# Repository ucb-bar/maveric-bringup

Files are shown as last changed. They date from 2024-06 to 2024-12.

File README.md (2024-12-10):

# Maveric Bringup

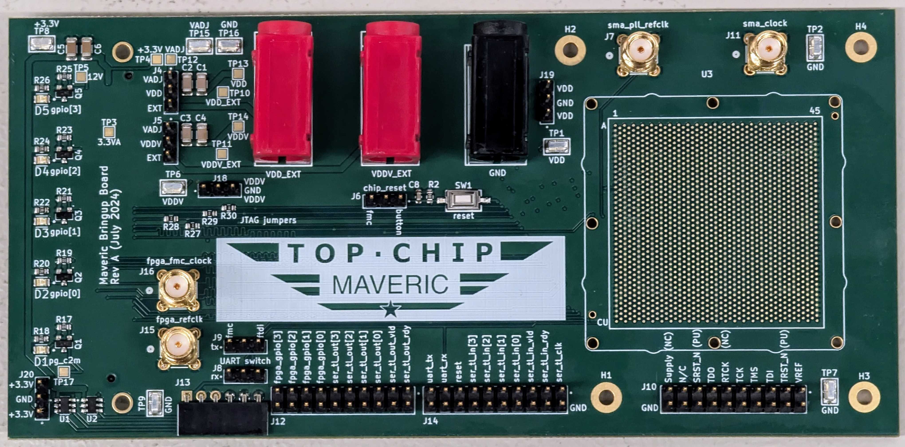
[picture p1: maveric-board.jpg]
Maveric Board


## Timeline

- 7/12 5pm: submitted order
- 7/12 7pm: review done
- 7/12 8pm: production files sent, confirmed
- 7/14 2am: parts placement sent, confirmed
- 7/18 7pm: board fab done
- 7/20 1am: board assembly done
- 7/21 8pm: shipped
- 7/23 2pm: delivered to BWRC
- Collaterals from JLCPCB are in `maveric-board/07_22_2024-jlcpcb`

## Test Plan

### FPGA Devboard

- Things to consider: cost, FPGA type, host interface, DRAM, connector + voltages, form factor
- Desires
  - Low cost (< $3k)
  - Small FPGA (fast bitstream generation and programming)
  - High bandwidth host interface (but NO PCIe / Ethernet, UART is OK but USB-FIFO is ideal)
  - Some DRAM, just 512 MiB is enough
  - FMC connector with board acting as carrier (FMC+ is OK, backwards compatible with FMC) (FMC-LPC is sufficient), 1.2V VADJ is necessary
  - Small board form factor
- [Xilinx VCU118](https://www.xilinx.com/products/boards-and-kits/vcu118.html)
  - $9k
  - Virtex Ultrascale+
  - USB-UART / PCIe with riser
  - 2x 2.5 Gib DDR4
  - FMC-HPC (ASP-134486-01), VADJ = 1.8V by default, can go down to 1.2V if FMC EEPROM is programmed or if system controller is overridden (intricate, but doable)
  - Large PCIe card
- [Opal Kelly XEM7350](https://opalkelly.com/products/xem7350/)
  - $1.5k
  - Kintex 7
  - USB3 with special RTL + drivers (Opal Kelly FrontPanel) with 340 MiB/s bandwidth
  - 512 MiB DDR3
  - FMC-HPC (-K160T part) (ASP-134486-01) (mates with ASP-134488-01), (34 (LA, Vadj) + 24 (HA, Vadj) + 22 (HB, Vio) = 80 IO pins), Vadj easy to set to 1.2V permanently, Vio comes from FMC_VIO_B_M2C (which can just be shorted to Vadj on the mezzanine)
  - Pretty small card
- [Digilent Nexys Video](https://digilent.com/shop/nexys-video-artix-7-fpga-trainer-board-for-multimedia-applications/)
  - $550
  - Artix 7
  - USB-UART / Ethernet / FT2232 (FTDI USB-FIFO chip, kind of an old part with iffy drivers)
  - 512 MiB DDR3
  - FMC-LPC (ASP-134603-01), 34x2 pins, Vadj set to 1.2V by default, easy

#### Mechanical Sketch

- [XEM7350 Mechanical Drawing](https://docs.opalkelly.com/wp-content/uploads/2022/05/XEM7350-MechanicalDrawing.pdf)
  - 4x standoffs for the FPGA devboard that exceed 6.5mm in height, 2.70mm hole diameter (use M2 standoff kit, M2 has clearance hole diameter of 2.6mm)
  - 2x standoffs for the chip motherboard that are likely around 18.5mm (will use same hole diameter)

### Chip Signals + Debug

[Bump map](https://bwrcrepo.eecs.berkeley.edu/kimsea8209/rtml-intech22-chipyard/-/blob/rtml-jerry/vlsi/specs/rtml-bumps.yml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) is saved in the `bumpmap` folder.
See the `README.md` in that folder for details.

#### Signals

- **JTAG**
  - Directly place the JTAG header on the motherboard. Don't daisy chain chip JTAG to FMC JTAG. Don't pass JTAG signals through FMC.
  - Use [this JTAG debugger](https://www.olimex.com/Products/ARM/JTAG/ARM-USB-OCD-HL/) (**-HL variant** works down to 0.65V)
    - [Digikey link](https://www.digikey.com/en/products/detail/olimex-ltd/ARM-USB-OCD-HL/21662466) ($58.79)
  - Use a USB optoisolator if we're scared
    - [Olimex link](https://www.olimex.com/Products/USB-Modules/USB-ISO/)
  - Standard [20-pin ARM JTAG header](https://developer.arm.com/documentation/101416/0100/Hardware-Description/Target-Interfaces/ARM-Standard-JTAG)
    - 2 rows × 10 pins at 0.1" step
    - [This will do, Digikey link](https://www.digikey.com/en/products/detail/sullins-connector-solutions/SBH11-PBPC-D10-ST-BK/1990065)
    - [Another Molex alternative that's much more expensive for some reason](https://www.digikey.com/en/products/detail/molex/0702462002/760185)
- **UART**
  1. Wire through FMC if we want to use the FPGA to drive chip UART
  2. Break out to headers to jump into the [Digilent Pmod USBUART](https://digilent.com/reference/pmod/pmodusbuart/reference-manual?redirect=1)
  - Requires level translation from 1.2V to 3.3V
  - Use jumpers to select between the 1) and 2) options for interacting with the chip via UART
    - Use standard 0.1" pitch 3x1 male headers and a shorting jumper for each wire (RX/TX)
    - [Shorting jumper - Digikey](https://www.digikey.com/en/products/detail/sullins-connector-solutions/QPC02SXGN-RC/2618262)
- **Serial TL**
  - Break out every signal (4 data + 1 valid + 1 ready = 6 pins/direction, 12+1 clock) to header pins via 0 Ohm resistor
  - Length match all signals roughly, within 10 mm
  - Make sure all signals land in same FPGA IO bank and land on pins with roughly the same [routing length on the devboard](https://pins.opalkelly.com/pin_list/XEM7350)
- **Chip reset**
  - Reset is active high. It is asynchronous. It is internally synchronized to the core clock domain on the falling reset edge.
  - Break out reset to header pin
  - ~~Drive a LED to indicate reset state with driver FET (make sure V_{gs,max} << 1.2V)~~ (bad idea to add more load on the reset net)

#### Clocking

- **Serial TL clock**
  - Always driven from FPGA FMC along with the rest of serial TL signals
  - No impedance control, but serial TL traces are roughly length matched (yeah I know this is overkill)
- **Core clock**
  - Can be driven by:
    1. FPGA via a regular GPIO pin over FMC
    2. External clock generator
  - Trace should have 50 Ohm impedance. Use SMAs to jump the FPGA clock to the chip clock and to receive the external clock (3x SMA total).
  - [Use shunt 50 Ohm termination near the chip clock pin](https://electronics.stackexchange.com/questions/646896/cannot-trigger-digital-logic-because-half-of-source-voltage-is-lost-in-impedance)
    - This works fine for the FPGA clock driver since it has low-Z output impedance. It will drive rail-to-rail 1.2Vpp at the chip.
    - This is a problem for the external clock generator since it has 50 Ohm series output impedance. It will drive 0.6Vpp at the chip nominally, so it will have to drive 2.4Vpp at the source for the chip to see 1.2Vpp.
- **PLL refclk**
  - Only comes from external clock generator with 50 Ohm driving impedance
  - Since it drives a high-Z IO cell, no termination is required, and Vpp on the generator should be set to 1.2V

#### Power

- Chip has 2 power inputs (VDD = core, VDDV = IO)
- VDDV and VDD can come from:
  1. External supply via banana plug (for current measurement)
  2. VADJ from FMC (nominally 1.2V) ()
  - Jumpers are used to select between 1) and 2)
- PCB considerations
  - Use 2 separate layers for VDD and VDDV so we can via directly to them from anywhere
  - Use 2 separate layers for GND
  - Front and back copper used for signal routing + ground pour
  - Route 3V3 FMC supply on top copper (we aren't using the other FMC supplies like 3V3AUX and 12V)
- Short all grounds together (FMC + banana plug ground)
- Headers for Vadj, VDD, GND, all FMC provided supplies

#### JTAG Pull-ups(downs)

Here is what all the various vendors have to say about JTAG pullup / pulldown resistors on JTAG nets from the target side.

- Xilinx
  - TDI + TMS pullup to VCC via 4.7k
  - TCK + TDO floating
- Altera
  - TDI + TMS weak pullup via 10k (TDI optional)
  - TCK weak pulldown via 1k
  - TDO floating
- ARM
  - TMS + TDI + TDO + nSRST + nTRST pullup
  - TCK pulldown
  - TRCK pulldown
  - All resistors should be 10k, except 4.7k for nSRST
- Lattice
  - TMS + TDI + TDO pullup via 4.7k
  - TCK pulldown via 4.7l
  - 100nF cap between VREF and GND near JTAG header

OK, after looking at all this conflicting information, I have made a decision.

- TMS + TDI + TDO pullup via 4.7k
- TCK pulldown via 4.7k
- RTCK floating
- TTRST_N + TSRST_N pullup via 4.7k (not going to chip, just in case the adapter wants to see these nets, this might be overkill and stupid)
- 100nF cap near connector on VREF
- Make sure all of these are easy to desolder if necessary

##### Decap

- Same strategy as hyperscale chip
- 10uF caps, 0603, place on backside of socket. Be wary of backside KOZ which are quite unusual.
- Use 100uF caps on VDD, VDDV, 3V3 supplies
- Use 10uF caps for decap near level shifters

### Chip Board to FPGA Connector

- Just use FMC, don't bother with adding the FMC EEPROM, loop FMC JTAG on the board with no daisy chaining, N/C FMC I2C
  - [FMC FAQ](https://www.vita.com/FMC-FAQ)
    - Attaching a LPC mezzanine to a HPC carrier is just fine as long as none of the HPC pins are used on the mezzanine
  - [Samtec's VITA 57.1 part picker](https://www.samtec.com/standards/vita/fmc/)
    - We can choose any HPC/LPC connector with/without leaded solder depending on what connectors are [in stock at JLCPCB](https://jlcpcb.com/parts/all-electronic-components)
- FMC powergood (C2M)
  - Add LED indicator + header probe point

## Schematic Review

- [x] Make sure all the chip IOs are represented and properly connected
  - ~~We seem to have used HSDIFF Q4 bumps (Hyperscale chip used HSDIFF Q3 for chip A and HSDIFF Q4 for chip B)~~
  - There are no clock taps, there isn't a `custom_boot` pin either
  - OH NO, I did make a mistake here. Refer to [this spreadsheet](https://docs.google.com/spreadsheets/d/1MSgKrY-m9DyHcFtSvew053FMCg2KrU9-J1SnmbLqwV8/edit#gid=0) for the correct mappings
- [x] Check clocking
  - [x] Is the PLL refclk terminated on-chip?
- [x] Verify UART directionality
- [x] Make sure power topology is correct
- [x] Make sure all debug functionality is available
- [x] Make sure decap is sufficient
- [x] Does the stackup look reasonable?
- [x] Is everything sane mechanically?

### Notes from Review

- [x] Add a 3 pin header to select reset coming from either FPGA or a button
- [x] 6 pin female header for PMOD USBUART
- [x] Add some more ground probe points (header pin + loop pin things) (4x around the PCB)
- [x] bring in JTAG signals onto the FPGA too via FMC
- [x] fix up the signal name mappings on the schematic
- [x] allocate one more layer for signal routing, combine VDD/VDDV into one layer
- [x] add holes next to FMC connector
- Length matching is unnecessary
- Support UART to Pmod through FPGA and with board headers directly
- Termination shouldn't cause any issues
- Make sure you have lots of test points, lots of ground test points too, make sure every probe for a signal has a short path to ground nearby
- Make sure the JTAG clock is exposed on a header pin
- Make sure you have standoffs near the FMC connector

## PCB CAD

### Considerations

- [Hyperscale test plan slides](https://docs.google.com/presentation/d/1U_Xe0r3WAxrghMTiEDUyeD21PqD4RekB/edit#slide=id.g2c498c81fbe_0_5S)
  - Contains some clocking and PLL and reset notes
- Plan is to use JLCPCB with 6+ layer 2mm board, 2U" ENIG, epoxy filled vias (if via-in-pad is required), 0.15mm min vias, uncontrolled impedance
  - Ideally I can relax the min via diameter, but it may not be possible with the fine BGA pitch. Via-in-pad might be necessary to make routing doable with few layers. Increase layers if required: maybe we can get away with 4 even.
  - Plan is to also do assembly with JLCPCB and get just fully assembled boards. I have verified all parts are in stock and all symbols on schematic are annotated with their 'JLCPCB Part #'.
- [JLCPCB PCB Design Rules](https://jlcpcb.com/capabilities/pcb-capabilities)
  - min 0.25mm BGA pads - OK
  - hole to hole clearance 0.5mm - OK
  - 0.09mm min trace width, 0.09 min trace spacing - seems sufficient for BGA escape
- [JLCPCB BGA Design Notes](https://jlcpcb.com/help/article/243-BGA-Design-Guidelines---PCB-Layout-Recommendations-for-BGA-packages)
  - 0.10mm min trace to BGA pad spacing
  - Everything still seems good enough
- [JLCPCB via-in-pad notes](https://jlcpcb.com/help/article/122-Via-Covering:-Tented,-Untented,-Plugged,-Epoxy-Filled-and-Copper-epoxy-filled)
  - 6+ layer boards come with epoxy filled vias for free! Pricing is insanely cheap for via-in-pad. Vias must be smaller than 0.5mm for full coverage.
- Someone has drafted [KiCad DRC rules for JLCPCB](https://gist.github.com/darkxst/f713268e5469645425eed40115fb8b49?permalink_comment_id=4818217) which I can use for reference
- Someone has tried to [escape a 0.5mm pitch BGA](https://www.eevblog.com/forum/altium/altium-jlcpcb-and-0-65mm-bga/) and it seems fine - just need to relax some design rules and make sure the hole clearance rule is specified correctly
- Another [via-in-pad attempt for 0.5mm pitch BGA](https://electronics.stackexchange.com/questions/676149/how-to-escape-0-5mm-ball-grid-array-pins) - seems possible with via-in-pad

### Stackup

- [JLCPCB Stackups](https://jlcpcb.com/impedance)
- 6 layer, 2mm thickness, 1oz outer copper weight, 0.5oz inner copper weight
- **Chosen Stackup**: JLC06201H-3313

| Layer | Material Type | Thickness | Purpose |
| --- | --- | --- | --- |
| F.Cu | Copper | 0.035mm | Signal, 3V3 (GND pour)|
| Prepreg | 3313*1 | 0.0994mm  | - |
| In1.Cu | Copper | 0.0152mm  | GND |
| Core | Core | 0.7mm | - |
| In2.Cu | Copper | 0.0152mm  | VDD, VDDV |
| Prepreg | 7628*1 | 0.2028mm  | - |
| In3.Cu | Copper | 0.0152mm  | Signal (GND pour) |
| Core | Core | 0.7mm | - |
| In4.Cu | Copper | 0.0152mm  | GND |
| Prepreg | 3313*1 | 0.0994mm  | - |
| B.Cu | Copper | 0.035mm | Signal (GND pour) |

- The stackup looks like (F.Cu, In1.Cu) | (In2.Cu, In3.Cu) | (In4.Cu, B.Cu) (i.e. 2-2-2)
- The first and third pairs are strongly coupled and the second pair has more separation

### Controlled Impedance Traces

- [JLCPCB Controlled Impedance Calculator](https://jlcpcb.com/pcb-impedance-calculator)
  - With the above stackup for 50 Ohm single-ended (non coplanar) (microstrip) on top copper with ground on In1.Cu
  - Trace width: **6.16 mils**

### Design Notes

#### UNI2 Socket

- Unit A-D: HSDIFF_{1-18}_{Q1-4}
- Unit E-H: IODIFF_{1-41}_{Q1-4}
- Unit I/J: Q1_{VDD, VDDV/VDDH}
- Unit K/L: Q2_{VDD, VDDV/VDDH}
- Unit M/N: Q3_{VDD, VDDV/VDDH}
- Unit O/P: Q4_{VDD, VDDV/VDDH}
- Unit Q-Y: VSS

#### FMC Terminal Selection

Possible parts [we can choose from](https://www.samtec.com/standards/vita/fmc/).
I would avoid tin-lead parts just because JLCPCB uses non-leaded solderpaste, and I'm unsure if reflow will work properly.
Also noting stock from JLCPCB.

- 8.5mm, lead-free, HPC: ASP-134602-01
  - 0 stock, $24.63 / part
- 8.5mm, lead-free, LPC: ASP-134606-01
  - 0 stock, $22.24 / part
- 10mm, lead-free, HPC: ASP-134488-01
  - 0 stock, listed as unavailable
- 10mm, lead-free, LPC: ASP-134604-01
  - 9 stock, $15.30 / part, still requires pre-order

- C2M = FPGA to motherboard = connector outputs
- M2C = motherboard to FPGA = connector inputs

#### FMC Pin to Socket Pin Mapping

- Use [XEM7350 Pins](https://pins.opalkelly.com/pin_list/XEM7350#) as reference for length matching. Keep all pins on the same FPGA IO bank ideally. We can choose from IO banks 15 or 16. We should keep to trace lengths (FMC socket to FPGA) around 80mm (78-82mm).

| Signal | FMC Net Name  | FMC Pin | Trace Length on XEM7350 (mm)  | FPGA IO Bank (XEM 7350) | FPGA Pin (XEM 7350) | FPGA Pin (Nexys Video)  | Notes |
| --- | --- | --- | --- | --- | --- | --- | --- |
| serial_tl_clock | LA_00_P_CC | G6 | 79.41 | 15 | H17 | K18 | |
| serial_tl_in_ready | LA_03_P | G9 | 79.53 | 15 | A18 | N18 | |
| serial_tl_in_valid | LA_03_N | G10 | 79.51 | 15 | A19 | N19 | |
| serial_tl_in_bits\[0\] | LA_06_P | C10 | 79.61 | 15 | C19 | N22 | |
| serial_tl_in_bits\[1\] | LA_06_N | C11 | 79.65 | 15 | B19 | M22 | |
| serial_tl_in_bits\[2\] | LA_10_P | C14 | 79.66 | 15 | B17 | K21 | |
| serial_tl_in_bits\[3\] | LA_10_N | C15 | 79.65 | 15 | A17 | K22 | |
| serial_tl_out_ready | LA_05_P | D11 | 78.61 | 15 | C17 | M21 | |
| serial_tl_out_valid | LA_05_N | D12 | 78.63 | 15 | C18 | L21 | |
| serial_tl_out_bits\[0\] | LA_09_P | D14 | 79.63 | 15 | L19 | H20 | |
| serial_tl_out_bits\[1\] | LA_09_N | D15 | 79.63 | 15 | L20 | G20 | |
| serial_tl_out_bits\[2\] | LA_15_P | H19 | 79.79 | 15 | K16 | L16 | |
| serial_tl_out_bits\[3\] | LA_15_N | H20 | 79.74 | 15 | K17 | K16 | |
| clock | LA_01_P_CC | D8 | 79.68 | 15 | G17 | J20 | via SMA cable jumper |
| reset | LA_21_P | H25 | 80.45 | 15 | G15 | E19 | |
| uart_rx | LA_02_P | H7 | 83.66 | 15 | G19 | M18 | via selection jumper |
| uart_tx | LA_02_N | H8 | 83.65 | 15 | F20 | L18 | via selection jumper |
| fpga_refclk | CLK0_M2C_P | H4 | 82.74 | 15 | E18 | J19 | to lock FPGA PLL to external clock source |
| fpga_gpio\[0\] | LA_14_P | C18 | 77.23 | 15 | H16 | J22 | to header + LED |
| fpga_gpio\[1\] | LA_14_N | C19 | 77.24 | 15 | G16 | H22 | to header + LED |
| fpga_gpio\[2\] | LA_27_P | C26 | 77.01 | 16 | D9 | B20 | to header + LED |
| fpga_gpio\[3\] | LA_27_N | C27 | 77.10 | 16 | D8 | A20 | to header + LED |
| jtag_tdi | LA_23_P | D23 | 81.08 | 16 | F14 | B21 | |
| jtag_tdo | LA_23_N | D24 | 81.09 | 16 | F13 | A21 | |
| jtag_tms | LA_26_P | D26 | 79.86 | 16 | C9 | F18 | |
| jtag_tck | LA_26_N | D27 | 79.82 | 16 | B9 | E18 | |

#### Extra Things to Buy

- Olimex JTAG debugger
- PMOD USB-UART
- A set of jumper cables (male to female)
- M2 standoff kit
- Header pin shorting jumpers
- FPGA devboard

#### Assembly Notes

- DNP the UNI2 socket
- Do not wave solder any through-hole components, hand-solder instead

## Tasks

- [x] Check FMC connector footprint [d:6/10]
  - [x] Dimension check: All dimensions check out, I drew some additional things on the silkscreen
  - [x] Solderpaste check: Specifically check solderpaste layer expansion. Pad 25 mils, soldermask expansion 4 mils (default, not that critical), solder paste 35 mils! So yes I adjusted the solder paste clearance.
- [x] Add FMC LPC symbol [d:6/10]
- [x] Wire FMC connector on schematic [d:6/10]
  - [x] Connect power supplies to globals and hierarchical outputs
  - [x] Add FPGA GPIOs
  - [x] Connect various things to GND / PWR
  - [x] Connect chip signals to FMC. Pin planning: want roughly equal delays on all serialtl nets.
  - [x] Add GND/VADJ drivers for unused FMC nets
    - Just to make sure FPGA can read things off the FMC connector
- [x] Add debug headers [d:6/10]
  - [x] 20pin header symbol + footprint + part
  - [x] 3pin header symbol + footprint + part
  - [x] 0 Ohm resistor symbol + footprint + part
  - [x] Add serialTL debug via 0Ohm resistors
  - [x] Add GPIO debug (direct)
- [x] Add terminal blocks for external supplies
  - [x] Add black banana plug symbol + footprint + part
  - [x] Add red banana plug symbol + footprint + part
- [x] Split FPGA and external supplies via jumper [d:6/12]
- [x] Add power domain probe points [d:6/12]
- [x] Add UART headers + jumpers [d:6/12]
- [x] Add UART level shifter [d:6/12]
- [x] Add JTAG headers
- [x] Add JLCPCB part for chip 10u decap
- [x] Add PG FPGA GPIO LEDs [d:6/14]
  - The LEDs on the hyperscale board seem like a waste. Seeing an 'on' LED for VDD doesn't prove anything lol.
  - I only care about the GPIOs and PG from the carrier to mezzanine (which are all slow signals)
  - No need to add an LED on the reset net, we already have a probe point which is sufficient (adding a LED will add NMOS gate cap and shunt resistor, which could retard the rise/fall time)
  - [x] Pick out all the components (2 resistors, MOSFET, LED)
  - [x] LED footprint + 3D
  - [x] MOSFET footprint + 3D
  - [x] Pick current limit resistor
- [x] Add clock nets with impedance control [d:6/14]
  - Fpga output impedance is uncontrolled (very low) impedance lvcmos12 IO standard
  - Terminate with shunt 50 Ohm that the Fpga can use
  - The clock generator will have to output 2x Vpp swing
  - [x] Sketch out clocking strategy
- [x] Add extra trigger refclk for the fpga pll to lock serial tl clock to core clock (if needed to mitigate async crossing issues) [d:6/16]
- [x] Add and check UNI2 socket footprint [d:6/16]
  - Check non-plated through holes, check pad spacing and diameter, check centerline
- [x] Add decap on power rails (VDD, VDDV, core + IO power domains, large decap) [d:6/16]
  - [x] Add decap on 3v3 rail too
  - [x] Add decap around level shifters too
- [x] Sketch out mechanical stuff of fpga devboard and chip board with fmc mating, describe standoffs + positions + hole diameters [d:6/16]
- [x] Add probe for FMC powergood (PG) [d:6/16]
- [x] Check that FMC powergood is actually at VADJ level (1.2V) [d:6/16]
  - Yes this seems to be the case (from checking ZC706 schematic)
- ~~[ ] Add clock probe pads~~
  - ???: Not a good idea when using shunt termination

### Final Re-Checks

- [x] Footprint and symbol finalization [d:6/16]
  - [x] Define custom MOSFET symbol to make sure pin numbers line up (for led driver)
  - [x] Define a custom LED symbol to make sure pin numbers line up with cathode/anode (for led driver)
- [x] Redo check of FMC symbol (pin name to pin coordinate mapping) [d:6/16]
- [x] Check chip IOs are represented and properly connected [d:6/16]
  - Against the Hyperscale schematic

### Post-Review Fixes

- [x] Fix chip IO mappings [d:6/19]
  - Refer to [this spreadsheet](https://docs.google.com/spreadsheets/d/1MSgKrY-m9DyHcFtSvew053FMCg2KrU9-J1SnmbLqwV8/edit#gid=0)
  - Delete all the garbage docs that confuse everyone
- [x] Import socket 3d model [d:6/21]
- [x] Fix reset circuit [d:6/21]
  - Add 3-pin header for reset selection + button
  - For the button path: pull down (1k || 100nF), button will pull reset high to VDDV
  - For the FPGA path: FPGA drives reset directly via FMC
  - [x] Add the switch 3d model + footprint
- [x] Add a 6-pin female header for plugging in the USBUART Pmod [d:6/19]
- [x] Add ground probe points around the PCB [d:6/19]
  - [x] Add 4x hook-style probes to GND around the board
  - [x] Sprinkle ground pins near every signal that can be probed
    - Just make sure every probe point has a ground pin nearby
- [x] Replace the supply probes header pins with hook-style probes [d:6/19]
- [x] Modify stackup to use one more layer for signal routing [d:6/19]
- [x] Bring JTAG signals onto the FPGA via FMC too [d:6/19]
- [x] Add mounting holes next to FMC connector [d:6/19]
- [x] Reexamine extended parts [d:6/21]
  - Try to convert to JLCPCB Basic parts if possible
  - There are 12 extended parts left
    - For SMT: level shifter, switch button, SMT testpoint, LED, FMC terminal, LED MOSFET driver
    - For through-hole (hand-soldered): black banana plug, red banana plug, 3 pin header, SMA connector, 20 pin header, 6 pin female header right-angle
    - 12 x \$2/extended part = \$24 assembly part fee
- [x] Reimport all symbols [d:6/21]
- [x] Reannotate schematic and push to layout [d:6/21]
- [x] Validate socket symbol [d:6/23]
  - Validate all the package coordinate to logical signal net mappings from the Intel schematic
  - I already found one error
  - We sent a mail to Brian casper on 6/21, let's see. I don't trust anything hand drawn unless I have the source.
  - Turns out there is no error. Assuming that `UNI2 ball map.csv` is golden, then the footprint + symbol are also perfect.

## Layout

### Setup

- [x] JLCPCB stackup + layer assignments [d:6/16]
- [x] JLCPCB constraints and design rules [d:6/16]
- [x] Import from schematic + placement [d:6/16]
- [x] Sketch edge cuts + standoff holes [d:6/16]
- [x] Verify 3d model placement of FMC [d:6/22]
  - FMC terminal footprint: <https://suddendocs.samtec.com/prints/seam-xx-xx.x-xx-xx-x-a-xx-footprint.pdf>
  - FMC terminal mechanical drawing: <https://suddendocs.samtec.com/prints/seam-xx-xx.x-xxx-xx-x-a-xx-k-xr-mkt.pdf>
  - Indeed the single tab is on the side of pin 1 and the double tabs are on the side of pin 40
- [x] Verify rotation and mounting and holes of FMC [d:6/22]
  - The mounting holes are biased towards the later letters as expected. Things look right.
- [x] Reimport from schematic [d:6/22]

### Routing

- [x] Route 3.3V [d:6/22]
- [x] Route VADJ
- [x] Route VDD_EXT
- [x] Route VDDV_EXT
- [x] Route all 50Ohm traces
- [x] Route all UART circuits
- [x] Route all JTAG pins
- [x] Route chip signal traces to FMC
- [x] Rip up 0.15mm vias [d:7/1]
- [x] Place and route decap [d:6/29]
- [x] Place Q3 vias [d:6/29]
- [x] Place all power/gnd vias [d:6/29]
- [x] Route chip signal probes [d:6/29]
- [x] Pour GND and route [d:6/29]
- [x] Pour VDD + VDDV [d:6/29]
- [x] Finish final routing + placement [d:7/1]
  - Route all remaining nets
- [x] Finalize holes [d:7/2]
  - [x] Convert M2.5 mounting holes to plated
  - [x] Convert FMC standoff holes to plated
    - Not going to convert the alignment holes - I think those are fine
  - [x] Convert socket holes to plated
  - [x] Import from symbols + import from schematic + place mounting holes
  - [x] Make sure no thermal reliefs on grounded holes
- [x] Adjust board dimensions and lock [d:7/2]

## Finalization

- [x] Add JLC silk
- ~~[ ] Look at G25~~
  - Use for routing VDDV around sma_clock
  - Actually I just rerouted sma_clock slightly to avoid this problem
- [x] Check DRC and connectivity
- [x] Check bottom clearance with 3D socket model
- [x] Separation between power planes [d:7/3]
  - Pull back power planes from board edge too
  - OK I performed some additional continuity hacking too, seems good
- [x] UART debugging help [d:7/3]
  - Ideally we should be able to test the level shifter and USB-UART Pmod without having the chip in place or even having a FMC connection to a FPGA
  - The only thing we need for that is to power VDDV and +3.3V
  - [x] Add extra header pins for 3.3V so we can drive it
- [x] JTAG debugging help [d:7/3]
  - [x] Add extra 3-pin headers for VDD and VDDV we can use for breadboarding hacks
  - [x] Add 0ohm jumpers for the JTAG FPGA traces to isolate FPGA if necessary
  - [x] Add pullup/pulldown resistor footprints (0603, DNP) on JTAG nets
  - [x] Recheck JTAG connector pinout (T vs R TCK)
- [x] Resync PCB and layout [d:7/3]
- [x] Clean all silks [d:7/3]
  - Placement, overlap, and text
  - DRC should be fully clean
- [x] Check that front assembly views exist for all footprints [d:7/3]
  - ~~The 3 pin header doesn't seem to have an assembly view~~ - actually scratch that, seems fine
- [x] Length match serial TL traces [d:7/3]
- [x] Add stiching vias for ground planes [d:7/3]
  - Throughout board
  - On edge of board
  - Around critical nets like clocks
  - Around 3.6k vias, under 4k via limit, will incur small extra charge due to drill density
- [x] Final check of LED current limit resistor [d:7/3]
  - Yeah looks good, why did Intel pick such a large resistor?
- [x] Get quote [d:7/4]
- [x] Cleanup schematic [d:7/4]
- [x] Redo models for banana plugs with easyeda models [d:7/4]
- [x] Add fun silk
- [x] Hide JLC silk under component [d:7/9]
- [x] Move J13 flush to board edge [d:7/9]
- [x] Nudge U2 away from hole [d:7/9]
- [x] Nudge C6 away from hole [d:7/9]
- [x] Check vertical clearance on XEM [d:7/9]
- [x] Check vertical clearance on Nexys Video [d:7/9]
  - Checked against Nexys Video step model, there is 5mm vertical clearance above PMOD connectors, horizontal clearance to the buttons is sufficient too

## Layout Review

### Questions

- Check silkscreen positions
- Check routing of critical nets
  - Clocks, serial TL
- Are plated thru-holes on the socket footprint OK?
- Is the decap sufficient and placed correctly?
- Check thermal reliefs on pours
- Check continuity and metal area on power pours

## Fab

- [x] Generate fresh fab files [d:7/10]
  - Check Gerbers locally again, BOM + CPL too
  - Commit to repo
  - [x] Commit copper/silk PDFs [d:7/9]
  - [x] Commit schematic [d:7/9]
- [x] Upload + get quote [d:7/10]
  - Make sure 3d render on JLCPCB side is perfect now
  - There are a few issues I think they will fix
    - U1/U2 are rotated 180deg
    - Q1-Q5 are not on their pads (also rotated 180deg)
    - Diodes look good
- [x] Get approval from PIs [d:7/10]
- [x] Purchase [d:7/11]
- [x] File for reimbursement [d:7/15]
- [x] Check on reimbursement [d:9/1]
  - Approved as of 8/11, not yet disbursed
  - Approved still on 8/21, still not yet disbursed
  - On 8/25, still nothing, bumped via email
- [x] Purchase heatsink + fan for xem7350 [d:8/15]
  - We have the EXX revision
  - https://opalkelly.com/products/#tab-accessories (FANSINK-30X30) which is $40 and is good
  - https://www.digikey.com/en/products/detail/molex/0878311420/662449 (just 1 quantity)
  - https://digilent.com/shop/jtag-hs2-programming-cable/

## XEM7350 Bringup

- [ ] Get Chipyard setup w/ metals working

## For Next Time

- Instead of using horizontal banana plug connectors, maybe use vertical ones instead
  - <https://www.reddit.com/r/ECE/comments/9wkrt6/where_to_buy_banana_jack_pcb_sockets/>
  - Actually better to just use screw terminals (<https://jlcpcb.com/partdetail/Ningbo_KangnexElec-WJ500V_5_083P/C72334>) that will save lots of board area
  - The highest stock Amphenol screw terminal: <https://jlcpcb.com/partdetail/AmphenolIcc-YO0301500000G/C2683167> (but it isn't in stock anywhere)
  - A preferred extended part: <https://jlcpcb.com/partdetail/Weco-930_DS02/C2974856>
  - Another good option: <https://jlcpcb.com/partdetail/PhoenixContact-1717732/C90080>
- Don't pre-assign the FMC pins, length matching isn't that important
  - Assign pins for ease of routing as we are routing them
  - Q3 header pins should be on top-side of board rather than bottom side
  - When doing hyperscale respin, Q4 debug pins should be on bottom side

## FPGA Bringup Design

### My Initial Lookover

- Using inout at FPGA top level is a very bad practice, makes it easy to make directionality mistakes
  - there are several mistakes, e.g. serial_tl_in_valid on the FPGA side is an *input*, but it is connected as an output
  - serial tl in/out need to be crossed!
  - but it won't affect pin mapping check, so it's likely ok for this check
- IOB packing (missing)
- ODDR for clock forwarding (chip clock + serial TL clock) (right now, there is no chip clock at all being generated from the FPGA)
- FPGA pll lock status (either as LED, or ideally as GPIO, + host MMIO reg)
- Reset synchronization is missing
- How is the TL serial clock divide ratio selected?
- UART TSI dropped is critical, we need to be sure it never goes high (use sticky register)
  - UART to TSI/TL state machine is less relevant
- Serial TSI interface is quite iffy
  - Switch to opposite edge clocking, need to add input/output delays for serial TL IOs
  - Need to pack all IOs in IOBs for good performance (you can often see electrical problems due to bad slewing if this isn't done)
  - No synchronization to the digital logic?
  - What clock is this block running at? It isn't oversampling (I think), so it must be running on the divided clock. Bad practice. Vivado isn't inferring the divided clock.
- Timing problems
  - Numerous problems related to CDC and missing / wrong constraints
  - MIG refclk seems wrong... maybe, at least Vivado reports a max period violation
    - Timing violations within MIG, not so marginal, would probably fail intermittently at least
  - Several unsynchronized CDC paths exist... particularly at MIG / ChipTop AXI boundary
  - FMC timing paths appear to be unconstrained, need to set bus_skew constraint or place all these signals on the same clock, Vivado isn't resolving this correctly
  - PLL clock feedback path unconstrained

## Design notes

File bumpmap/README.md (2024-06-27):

These files [came from this branch](https://bwrcrepo.eecs.berkeley.edu/kimsea8209/rtml-intech22-chipyard/-/tree/rtml-jerry/vlsi/specs).

## Files

- `ken-bumps.yml` was the bumpmap for the hyperscale chip with the 2 ChipTop's inside
- The `read-yml.py` script reads `ken-bumps.yml` and hacks it to create `rtml-bumps.yml`
  - `rtml-bumps.yml` is what we should reference for the chip bumps
- `rtml-design.yml` is the hammer yaml file for the chip, but it seems a bit stale. Shouldn't need to reference it.
- `C4 Bump map for UNI2 package.xlsx` contains the mappings from the chip bump (x, y) coordinate to the logical net name
  - **WARNING**: the (x, y) coordinates DO NOT correspond to the (column, row) coordinates in the spreadsheet!!!
- **Actually**, refer to [this sheet](https://docs.google.com/spreadsheets/d/1MSgKrY-m9DyHcFtSvew053FMCg2KrU9-J1SnmbLqwV8/edit?usp=sharing) (`Hyperscale 4x4 Package.xlsx`) which contains the clear and correct chip bump (x, y) to signal name mapping

## Mapping

| (chip bump x, chip bump y) | Design signal name | Direction (from chip perspective) | Package/socket signal name |
| --- | --- | --- | --- |
| (1, 12) | uart_rx | input | HSDIFF_16_N_Q3  |
| (1, 14) | jtag_tdo | output  | HSDIFF_15_N_Q3  |
| (1, 16) | serial_tl_in\[3\] | input | HSDIFF_14_N_Q3  |
| (1, 18) | serial_tl_out_ready | input | HSDIFF_13_N_Q3  |
| (1, 20) | serial_tl_out\[1\] | output  | HSDIFF_12_N_Q3  |
| (1, 22) | clock | input | HSDIFF_11_N_Q3  |
| (2, 13) | jtag_tms | input | HSDIFF_16_P_Q3  |
| (2, 15) | serial_tl_in_ready | output  | HSDIFF_15_P_Q3  |
| (2, 17) | serial_tl_in\[1\] | input | HSDIFF_14_P_Q3  |
| (2, 19) | serial_tl_out\[3\] | output  | HSDIFF_13_P_Q3  |
| (2, 23) | pll_refclk | input | HSDIFF_11_P_Q3  |
| (4, 13) | jtag_tck | input | HSDIFF_7_P_Q3 |
| (4, 15) | serial_tl_clock | input | HSDIFF_6_P_Q3 |
| (4, 17) | serial_tl_in\[2\] | input | HSDIFF_5_P_Q3 |
| (4, 19) | serial_tl_out_valid | output  | HSDIFF_4_P_Q3 |
| (4, 21) | serial_tl_out\[0\] | output  | HSDIFF_3_P_Q3 |
| (5, 12) | uart_tx | output  | HSDIFF_7_N_Q3 |
| (5, 14) | jtag_tdi | input | HSDIFF_6_N_Q3 |
| (5, 16) | serial_tl_in_valid | input | HSDIFF_5_N_Q3 |
| (5, 18) | serial_tl_in\[0\] | input | HSDIFF_4_N_Q3 |
| (5, 20) | serial_tl_out\[2\] | output  | HSDIFF_3_N_Q3 |
| (5, 22) | reset | input | HSDIFF_2_N_Q3 |

## Symbol Validation

Now let's discuss the physical bump layout.

For the C4 bumps on the chip, the quadrants are as such (bumps on top):

| Q4 | Q2 |
| -- | -- |
| Q3 | Q1 |

Then, this chip is flipped onto the package on the vertical-axis so the bumps look like this (package balls on bottom):

| Q2 | Q4 |
| -- | -- |
| Q1 | Q3 |

This is the layout assumed by the `UNI2 ball map.csv` file, which we use to validate the net name to package/socket coordinate mapping.
CRITICALLY, the origin is at the center of the package and the positive y-axis goes up and the positive x-axis goes right.

Then, the package is rotated by 180 degrees so that Q3 appears in the upper right quadrant.
This requires a coordinate transformation (x, y) -> (new x, new y):

- (+, +) → (-, -)
- (+, -) → (-, +)
- (-, +) → (+, -)
- (-, -) → (+, +)
- This is just sign inversion

| Q3 | Q1 |
| -- | -- |
| Q4 | Q2 |

One note: the balls on the socket are shifted right by 0.375mm relative to the package center origin, so we must compensate for that when parsing the socket footprint.
CRITICALLY, the socket footprint has a different coordinate axis! The positive y-axis goes down and the positive x-axis goes right.
This requires another coordinate transformation (x, y) -> (new x, new y):

- (+, +) → (+, -)
- (+, -) → (+, +)
- (-, +) → (-, -)
- (-, -) → (-, +)
- This is just flipping the sign of the y coordinate

At this point, we have the (x, y) location to net name mapping which we check against the footprint + symbol.

```
python -m venv venv
source venv/bin/activate
pip install sexpdata
./extract_pads --footprint ../maveric-board/maveric-parts.pretty/BGA-1733-.92-47.725x47.725.kicad_mod --symbol-name TESTCHIP_UNI2 --symbol-lib ../maveric-board/maveric-parts.kicad_sym --reference-csv UNI2\ ball\ map.csv
```

This script does the symbol validation.
It parses the socket footprint to get the pad positions (in mm) and pad coordinate (e.g. AN13).
It parses the symbol to get the mapping of pad coordinate to net name (HSDIFF...).
It parses the reference CSV to get the mapping of net name to pad position (bump coordinate in mm).
It checks that everything matches up. And indeed everything matches up.

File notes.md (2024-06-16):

# Maveric Bringup

## Strategy

### FPGA Devboard

- Things to consider: cost, FPGA type, host interface, DRAM, connector + voltages, form factor
- [Xilinx VCU118](https://www.xilinx.com/products/boards-and-kits/vcu118.html)
  - $9k
  - Virtex Ultrascale+
  - USB-UART / PCIe with riser
  - 2x 2.5 Gib DDR4
  - FMC-HPC (ASP-134486-01), VADJ = 1.8V by default, can go down to 1.2V if FMC EEPROM is programmed or if system controller is overridden (intricate, but doable)
  - Large PCIe card
- [Opal Kelly XEM7350](https://opalkelly.com/products/xem7350/)
  - $1.5k
  - Kintex 7
  - USB3 with special RTL + drivers (Opal Kelly FrontPanel) with 340 MiB/s bandwidth
  - 512 MiB DDR3
  - FMC-HPC (-K160T part) (ASP-134486-01) (mates with ASP-134488-01), (34 (LA, Vadj) + 24 (HA, Vadj) + 22 (HB, Vio) = 80 IO pins), Vadj easy to set to 1.2V permanently, Vio comes from FMC_VIO_B_M2C (which can just be shorted to Vadj on the mezzanine)
  - Pretty small card
- [Digilent Nexys Video](https://digilent.com/shop/nexys-video-artix-7-fpga-trainer-board-for-multimedia-applications/)
  - $550
  - Artix 7
  - USB-UART / Ethernet / FT2232 (FTDI USB-FIFO chip, kind of an old part with iffy drivers)
  - 512 MiB DDR3
  - FMC-LPC (ASP-134603-01), 34x2 pins, Vadj set to 1.2V by default, easy

#### Mechanical Sketch

- https://docs.opalkelly.com/wp-content/uploads/2022/05/XEM7350-MechanicalDrawing.pdf
  - 4x standoffs for the FPGA devboard that exceed 6.5mm in height, 2.70mm hole diameter (use M2 standoff kit, M2 has clearance hole diameter of 2.6mm)
  - 2x standoffs for the chip motherboard that are likely around 18.5mm (will use same hole diameter)

### Chip Signals + Debug

[Bump map](https://bwrcrepo.eecs.berkeley.edu/kimsea8209/rtml-intech22-chipyard/-/blob/rtml-jerry/vlsi/specs/rtml-bumps.yml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) is saved in the `bumpmap` folder.

#### Signals

- **JTAG**
  - Directly place the JTAG header on the motherboard. Don't daisy chain chip JTAG to FMC JTAG. Don't pass JTAG signals through FMC.
  - Use [this JTAG debugger](https://www.olimex.com/Products/ARM/JTAG/ARM-USB-OCD-HL/) (**-HL variant** works down to 0.65V)
    - [Digikey link](https://www.digikey.com/en/products/detail/olimex-ltd/ARM-USB-OCD-HL/21662466) ($58.79)
  - Use a USB optoisolator if we're scared
    - [Olimex link](https://www.olimex.com/Products/USB-Modules/USB-ISO/)
  - Standard [20-pin ARM JTAG header](https://developer.arm.com/documentation/101416/0100/Hardware-Description/Target-Interfaces/ARM-Standard-JTAG)
    - 2 rows × 10 pins at 0.1" step
    - [This will do, Digikey link](https://www.digikey.com/en/products/detail/sullins-connector-solutions/SBH11-PBPC-D10-ST-BK/1990065)
    - [Another Molex alternative that's much more expensive for some reason](https://www.digikey.com/en/products/detail/molex/0702462002/760185)
- **UART**
  1. Wire through FMC if we want to use the FPGA to drive chip UART
  2. Break out to headers to jump into the [Digilent Pmod USBUART](https://digilent.com/reference/pmod/pmodusbuart/reference-manual?redirect=1)
    - Requires level translation from 1.2V to 3.3V
  - Use jumpers to select between the 1) and 2) options for interacting with the chip via UART
    - Use standard 0.1" pitch 3x1 male headers and a shorting jumper for each wire (RX/TX)
    - [Shorting jumper - Digikey](https://www.digikey.com/en/products/detail/sullins-connector-solutions/QPC02SXGN-RC/2618262)
- **Serial TL**
  - Break out every signal (4 data + 1 valid + 1 ready = 6 pins/direction, 12+1 clock) to header pins via 0 Ohm resistor
  - Length match all signals roughly, within ~5-10 mm
  - Make sure all signals land in same FPGA IO bank and land on pins with roughly the same [routing length on the devboard](https://pins.opalkelly.com/pin_list/XEM7350)
- **Chip reset**
  - Reset is active high. It is asynchronous. It is internally synchronized to the core clock domain on the falling reset edge.
  - Break out reset to header pin
  - ~~Drive a LED to indicate reset state with driver FET (make sure V_{gs,max} << 1.2V)~~ (bad idea to add more load on the reset net)

#### Clocking

- **Serial TL clock**
  - Always driven from FPGA FMC along with the rest of serial TL signals
  - No impedance control, but serial TL traces are roughly length matched
- **Core clock**
  - Can be driven by:
    1. FPGA via a regular GPIO pin over FMC
    2. External clock generator
  - Trace should have 50 Ohm impedance. Use SMAs to jump the FPGA clock to the chip clock and to receive the external clock (3x SMA total).
  - [Use shunt 50 Ohm termination near the chip clock pin](https://electronics.stackexchange.com/questions/646896/cannot-trigger-digital-logic-because-half-of-source-voltage-is-lost-in-impedance)
    - This works fine for the FPGA clock driver since it has low-Z output impedance. It will drive rail-to-rail 1.2Vpp at the chip.
    - This is a problem for the external clock generator since it has 50 Ohm series output impedance. It will drive 0.6Vpp at the chip nominally, so it will have to drive 2.4Vpp at the source for the chip to see 1.2Vpp.
- **PLL refclk**
  - Only comes from external clock generator with 50 Ohm driving impedance
  - Since it drives a high-Z GPIO, no termination is required, and Vpp on the generator should be set to 1.2V

#### Power

- Chip has 2 power inputs (VDD = core, VDDV = IO)
- VDDV and VDD can come from:
  1. External supply via banana plug (for current measurement)
  2. VADJ from FMC (nominally 1.2V) ()
  - Jumpers are used to select between 1) and 2)
- PCB considerations
  - Use 2 separate layers for VDD and VDDV so we can via directly to them from anywhere
  - Use 2 separate layers for GND
  - Front and back copper used for signal routing + ground pour
  - Route 3V3 FMC supply on top copper (we aren't using the other FMC supplies like 3V3AUX and 12V)
- Short all grounds together (FMC + banana plug ground)
- Headers for Vadj, VDD, GND, all FMC provided supplies

##### Decap

- Same strategy as hyperscale chip
- 10uF caps, 0603, place on backside of socket. Be wary of backside KOZ which are quite unusual.
- Use 100uF caps on VDD, VDDV, 3V3 supplies
- Use 10uF caps for decap near level shifters

### Chip Board to FPGA Connector

- Just use FMC, don't bother with adding the FMC EEPROM, loop FMC JTAG on the board with no daisy chaining, N/C FMC I2C
  - [FMC FAQ](https://www.vita.com/FMC-FAQ)
    - Attaching a LPC mezzanine to a HPC carrier is just fine as long as none of the HPC pins are used on the mezzanine
  - [Samtec's VITA 57.1 part picker](https://www.samtec.com/standards/vita/fmc/)
    - We can choose any HPC/LPC connector with/without leaded solder depending on what connectors are [in stock at JLCPCB](https://jlcpcb.com/parts/all-electronic-components)
- FMC powergood (C2M)
  - Add LED indicator + header probe point

## PCB CAD

### Considerations

- [Hyperscale test plan slides](https://docs.google.com/presentation/d/1U_Xe0r3WAxrghMTiEDUyeD21PqD4RekB/edit#slide=id.g2c498c81fbe_0_5S)
  - Contains some clocking and PLL and reset notes
- Plan is to use JLCPCB with 6+ layer 2mm board, 2U" ENIG, epoxy filled vias (if via-in-pad is required), 0.15mm min vias, uncontrolled impedance
  - Ideally I can relax the min via diameter, but it may not be possible with the fine BGA pitch. Via-in-pad might be necessary to make routing doable with few layers. Increase layers if required: maybe we can get away with 4 even.
  - Plan is to also do assembly with JLCPCB and get just fully assembled boards. Might need to special order FMC terminals, but otherwise OK
- [JLCPCB PCB Design Rules](https://jlcpcb.com/capabilities/pcb-capabilities)
  - min 0.25mm BGA pads - OK
  - hole to hole clearance 0.5mm - OK
  - 0.09mm min trace width, 0.09 min trace spacing - seems sufficient for BGA escape
  - Everything looks good enough, no need for fancy board house
- [JLCPCB BGA Design Notes](https://jlcpcb.com/help/article/243-BGA-Design-Guidelines---PCB-Layout-Recommendations-for-BGA-packages)
  - 0.10mm min trace to BGA pad spacing
  - Everything still seems good enough
- [JLCPCB via-in-pad notes](https://jlcpcb.com/help/article/122-Via-Covering:-Tented,-Untented,-Plugged,-Epoxy-Filled-and-Copper-epoxy-filled)
  - 6+ layer boards come with epoxy filled vias for free! Pricing is insanely cheap for via-in-pad. Vias must be smaller than 0.5mm for full coverage.
- Someone has drafted [KiCad DRC rules for JLCPCB](https://gist.github.com/darkxst/f713268e5469645425eed40115fb8b49?permalink_comment_id=4818217) which I can use for reference
- Someone has tried to [escape a 0.5mm pitch BGA](https://www.eevblog.com/forum/altium/altium-jlcpcb-and-0-65mm-bga/) and it seems fine - just need to relax some design rules and make sure the hole clearance rule is specified correctly
- Another [via-in-pad attempt for 0.5mm pitch BGA](https://electronics.stackexchange.com/questions/676149/how-to-escape-0-5mm-ball-grid-array-pins) - seems possible with via-in-pad

### Stackup

- [JLCPCB Stackups](https://jlcpcb.com/impedance)
- 6 layer, 2mm thickness, 1oz outer copper weight, 0.5oz inner copper weight
- **Stackup name**: JLC06201H-3313

| Layer | Material Type | Thickness | Purpose |
| --- | --- | --- | --- |
| F.Cu | Copper | 0.035mm | Signal, 3V3 |
| Prepreg | 3313*1 | 0.0994mm  | - |
| In1.Cu | Copper | 0.0152mm  | GND |
| Core | Core | 0.7mm | - |
| In2.Cu | Copper | 0.0152mm  | VDD |
| Prepreg | 7628*1 | 0.2028mm  | - |
| In3.Cu | Copper | 0.0152mm  | GND |
| Core | Core | 0.7mm | - |
| In4.Cu | Copper | 0.0152mm  | VDDV, Signal |
| Prepreg | 3313*1 | 0.0994mm  | - |
| B.Cu | Copper | 0.035mm | GND |

- The stackup looks like (F.Cu, In1.Cu) | (In2.Cu, In3.Cu) | (In4.Cu, B.Cu)
- The first and third pairs are strongly coupled and the second pair has more separation
- [See this video](https://www.youtube.com/watch?v=60RxCiZuD9E)
  - Only need a ground via when going from layer 1 to 5

### Controlled Impedance Traces

- [JLCPCB Controlled Impedance Calculator](https://jlcpcb.com/pcb-impedance-calculator)
  - With the above stackup for 50 Ohm single-ended (non coplanar) on top copper with ground on In2.Cu
  - Trace width: **6.16 mils**

### Design Notes

#### UNI2 Socket

- Unit A-D: HSDIFF_{1-18}_{Q1-4}
- Unit E-H: IODIFF_{1-41}_{Q1-4}
- Unit I/J: Q1_{VDD, VDDV/VDDH}
- Unit K/L: Q2_{VDD, VDDV/VDDH}
- Unit M/N: Q3_{VDD, VDDV/VDDH}
- Unit O/P: Q4_{VDD, VDDV/VDDH}
- Unit Q-Y: VSS

#### FMC Terminal Selection

Possible parts [we can choose from](https://www.samtec.com/standards/vita/fmc/).
I would avoid tin-lead parts just because JLCPCB uses non-leaded solderpaste, and I'm unsure if reflow will work properly.
Also noting stock from JLCPCB.

- 8.5mm, lead-free, HPC: ASP-134602-01
    - 0 stock, $24.63 / part
- 8.5mm, lead-free, LPC: ASP-134606-01
    - 0 stock, $22.24 / part
- 10mm, lead-free, HPC: ASP-134488-01
    - 0 stock, listed as unavailable
- 10mm, lead-free, LPC: ASP-134604-01
    - 9 stock, $15.30 / part, still requires pre-order

- C2M = FPGA to motherboard = connector outputs
- M2C = motherboard to FPGA = connector inputs

#### FMC Pin to Socket Pin Mapping

- Use [XEM7350 Pins](https://pins.opalkelly.com/pin_list/XEM7350#) as reference for length matching. Keep all pins on the same FPGA IO bank ideally. We can choose from IO banks 15 or 16. We should keep to trace lengths (FMC socket to FPGA) around 80mm (78-82mm).

| Signal | FMC Net Name  | FMC Pin | Trace Length on XEM7350 (mm)  | FPGA IO Bank  | FPGA Pin  | Notes |
| --- | --- | --- | --- | --- | --- | --- |
| serial_tl_clock | LA_00_P_CC | G6 | 79.41 | 15 | H17 | |
| serial_tl_in_ready | LA_03_P | G9 | 79.53 | 15 | A18 | |
| serial_tl_in_valid | LA_03_N | G10 | 79.51 | 15 | A19 | |
| serial_tl_in_bits\[0\] | LA_06_P | C10 | 79.61 | 15 | C19 | |
| serial_tl_in_bits\[1\] | LA_06_N | C11 | 79.65 | 15 | B19 | |
| serial_tl_in_bits\[2\] | LA_10_P | C14 | 79.66 | 15 | B17 | |
| serial_tl_in_bits\[3\] | LA_10_N | C15 | 79.65 | 15 | A17 | |
| serial_tl_out_ready | LA_05_P | D11 | 78.61 | 15 | C17 | |
| serial_tl_out_valid | LA_05_N | D12 | 78.63 | 15 | C18 | |
| serial_tl_out_bits\[0\] | LA_09_P | D14 | 79.63 | 15 | L19 | |
| serial_tl_out_bits\[1\] | LA_09_N | D15 | 79.63 | 15 | L20 | |
| serial_tl_out_bits\[2\] | LA_15_P | H19 | 79.79 | 15 | K16 | |
| serial_tl_out_bits\[3\] | LA_15_N | H20 | 79.74 | 15 | K17 | |
| clock | LA_01_P_CC | D8 | 79.68 | 15 | G17 | via SMA cable jumper |
| reset | LA_21_P | H25 | 80.45 | 15 | G15 | |
| uart_rx | LA_20_P | G21 | 81.48 | 15 | L17 | via selection jumper |
| uart_tx | LA_20_N | G22 | 81.48 | 15 | K18 | via selection jumper |
| fpga_gpio\[0\] | LA_13_P | D17 | 81.70 | 15 | E15 | to header + LED |
| fpga_gpio\[1\] | LA_13_N | D18 | 81.70 | 15 | E16 | to header + LED |
| fpga_gpio\[2\] | LA_25_P | G27 | 82.45 | 15 | J15 | to header + LED |
| fpga_gpio\[3\] | LA_25_N | G28 | 82.46 | 15 | J16 | to header + LED |
| fpga_refclk | CLK0_M2C_P | H4 | 82.74 | 15 | E18 | for locking FPGA PLL to external clock source |

#### Extra Things to Buy

- Olimex JTAG debugger
- PMOD USB-UART
- A set of jumper cables (male to female)
- M2 standoff kit
- Header pin jumpers
- FPGA devboard

#### Assembly Notes

- DNP the UNI2 socket
- Do not wave solder any through-hole components, hand-solder instead

## Tasks

- [x] Check FMC connector footprint [d:6/10]
  - [x] Dimension check: All dimensions check out, I drew some additional things on the silkscreen
  - [x] Solderpaste check: Specifically check solderpaste layer expansion. Pad 25 mils, soldermask expansion 4 mils (default, not that critical), solder paste 35 mils! So yes I adjusted the solder paste clearance.
- [x] Add FMC LPC symbol [d:6/10]
- [x] Wire FMC connector on schematic [d:6/10]
  - [x] Connect power supplies to globals and hierarchical outputs
  - [x] Add FPGA GPIOs
  - [x] Connect various things to GND / PWR
  - [x] Connect chip signals to FMC. Pin planning: want roughly equal delays on all serialtl nets.
  - [x] Add GND/VADJ drivers for unused FMC nets
    - Just to make sure FPGA can read things off the FMC connector
- [x] Add debug headers [d:6/10]
  - [x] 20pin header symbol + footprint + part
  - [x] 3pin header symbol + footprint + part
  - [x] 0 Ohm resistor symbol + footprint + part
  - [x] Add serialTL debug via 0Ohm resistors
  - [x] Add GPIO debug (direct)
- [x] Add terminal blocks for external supplies
  - [x] Add black banana plug symbol + footprint + part
  - [x] Add red banana plug symbol + footprint + part
- [x] Split FPGA and external supplies via jumper [d:6/12]
- [x] Add power domain probe points [d:6/12]
- [x] Add UART headers + jumpers [d:6/12]
- [x] Add UART level shifter [d:6/12]
- [x] Add JTAG headers
- [x] Add JLCPCB part for chip 10u decap
- [x] Add PG FPGA GPIO LEDs [d:6/14]
  - The LEDs on the hyperscale board seem like a waste. Seeing an 'on' LED for VDD doesn't prove anything lol.
  - I only care about the GPIOs and PG from the carrier to mezzanine (which are all slow signals)
  - No need to add an LED on the reset net, we already have a probe point which is sufficient (adding a LED will add NMOS gate cap and shunt resistor, which could retard the rise/fall time)
  - [x] Pick out all the components (2 resistors, MOSFET, LED)
  - [x] LED footprint + 3D
  - [x] MOSFET footprint + 3D
  - [x] Pick current limit resistor
- [x] Add clock nets with impedance control [d:6/14]
  - Fpga output impedance is uncontrolled (very low) impedance lvcmos12 IO standard
  - Terminate with shunt 50 Ohm that the Fpga can use
  - The clock generator will have to output 2x Vpp swing
  - [x] Sketch out clocking strategy
- [x] Add extra trigger refclk for the fpga pll to lock serial tl clock to core clock (if needed to mitigate async crossing issues) [d:6/16]
- [x] Add and check UNI2 socket footprint [d:6/16]
  - Check non-plated through holes, check pad spacing and diameter, check centerline
- [x] Add decap on power rails (VDD, VDDV, core + IO power domains, large decap) [d:6/16]
  - [x] Add decap on 3v3 rail too
  - [x] Add decap around level shifters too
- [x] Sketch out mechanical stuff of fpga devboard and chip board with fmc mating, describe standoffs + positions + hole diameters [d:6/16]
- [x] Add probe for FMC powergood (PG) [d:6/16]
- [x] Check that FMC powergood is actually at VADJ level (1.2V) [d:6/16]
  - Yes this seems to be the case (from checking ZC706 schematic)
- ~~[ ] Add clock probe pads~~
  - ???: Not a good idea when using shunt termination

### Final Re-Checks

- [x] Footprint and symbol finalization [d:6/16]
  - [x] Define custom MOSFET symbol to make sure pin numbers line up (for led driver)
  - [x] Define a custom LED symbol to make sure pin numbers line up with cathode/anode (for led driver)
- [x] Redo check of FMC symbol (pin name to pin coordinate mapping) [d:6/16]
- [x] Check chip IOs are represented and properly connected [d:6/16]
  - Against the Hyperscale schematic

### Things to Check During Review

- [ ] Make sure all the chip IOs are represented and properly connected
  - We seem to have used HSDIFF Q4 bumps (Hyperscale chip used HSDIFF Q3 for chip A and HSDIFF Q4 for chip B)
  - There are no clock taps, there isn't a `custom_boot` pin either
- [ ] Check clocking
  - [ ] Is the PLL refclk terminated on-chip?
- [ ] Verify UART directionality
- [ ] Make sure power topology is correct
- [ ] Make sure all debug functionality is available
- [ ] Make sure decap is sufficient
- [ ] Does the stackup look reasonable?
- [ ] Is everything sane mechanically?

## Layout

- [ ] Add stiching vias for ground planes

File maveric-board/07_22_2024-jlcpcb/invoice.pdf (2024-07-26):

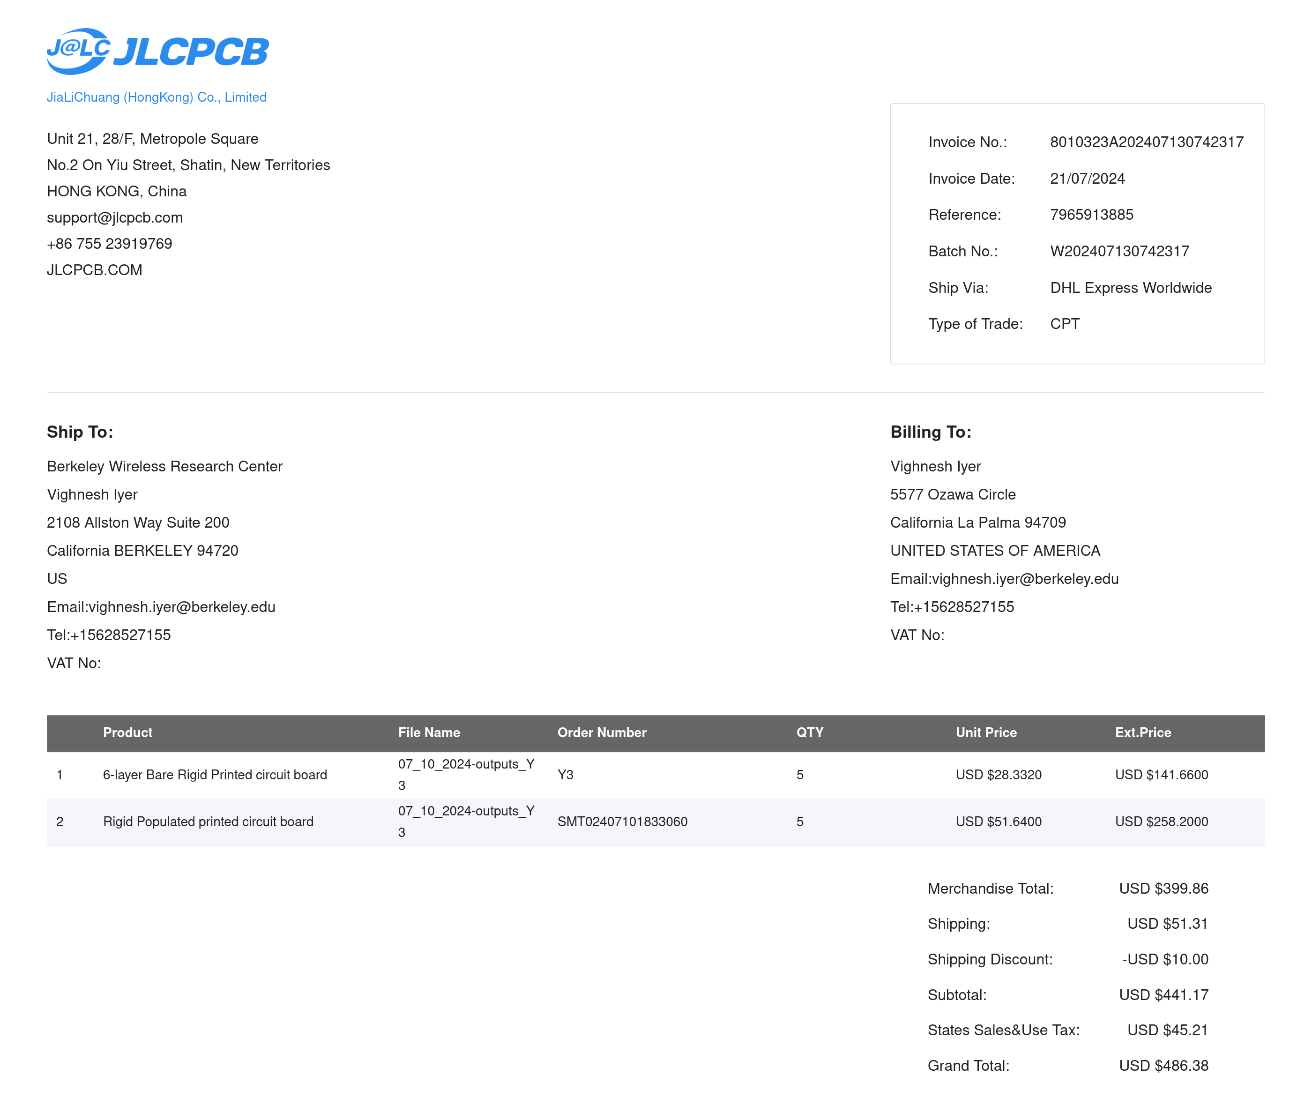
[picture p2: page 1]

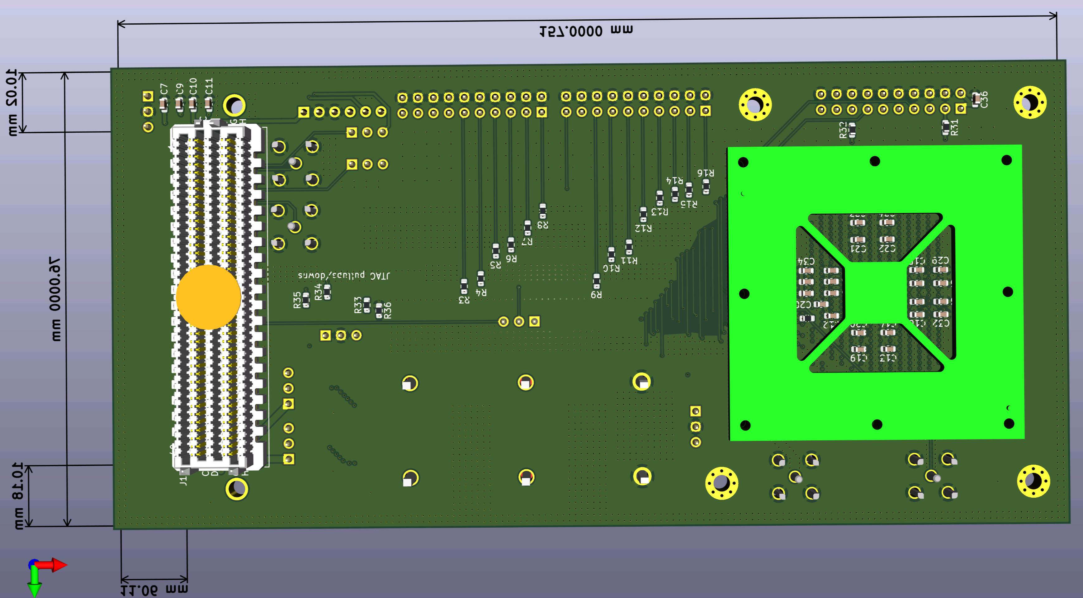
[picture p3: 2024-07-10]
maveric-board/07_10_2024-quote/board_3d_view_bottom.png

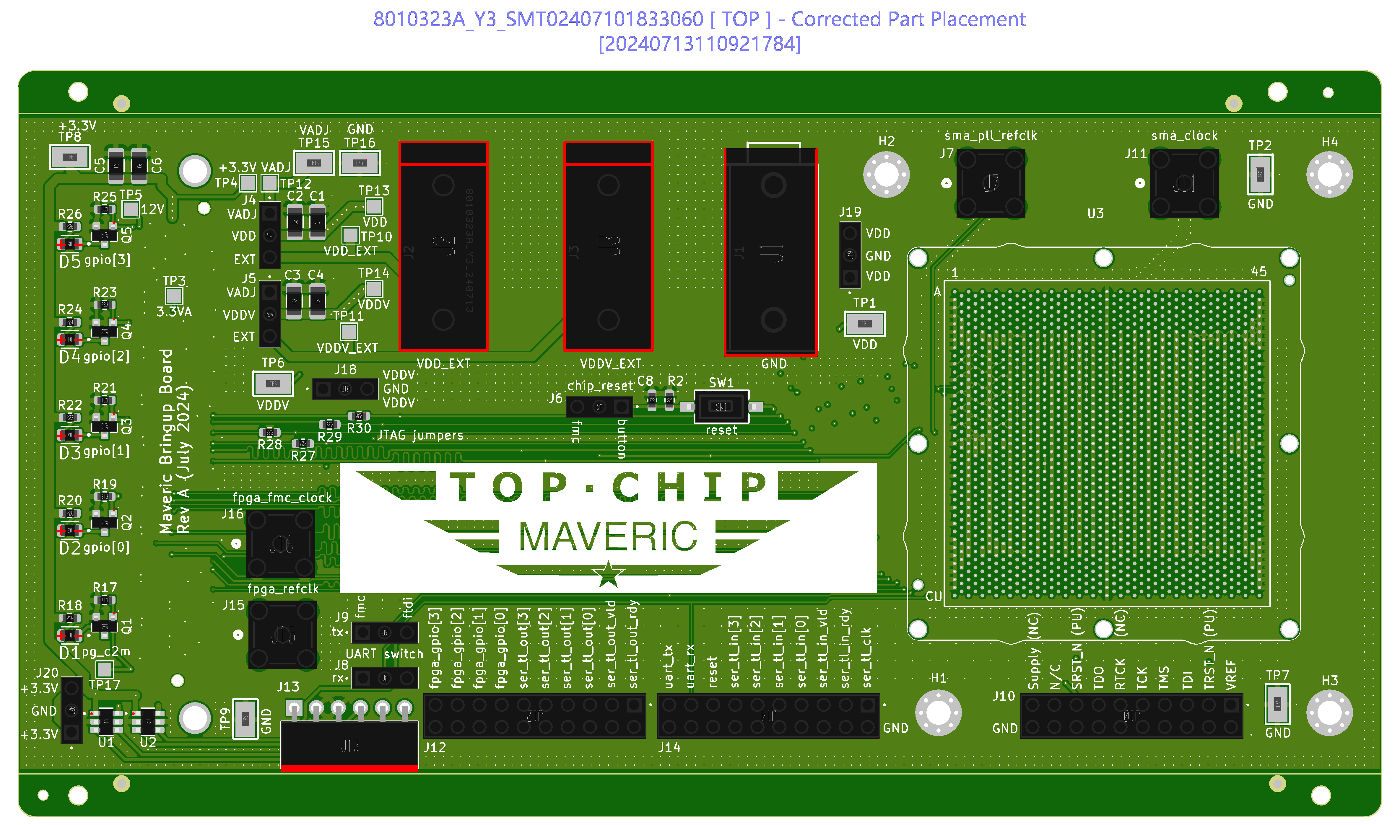
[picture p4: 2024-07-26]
maveric-board-docs/top-dfm.png

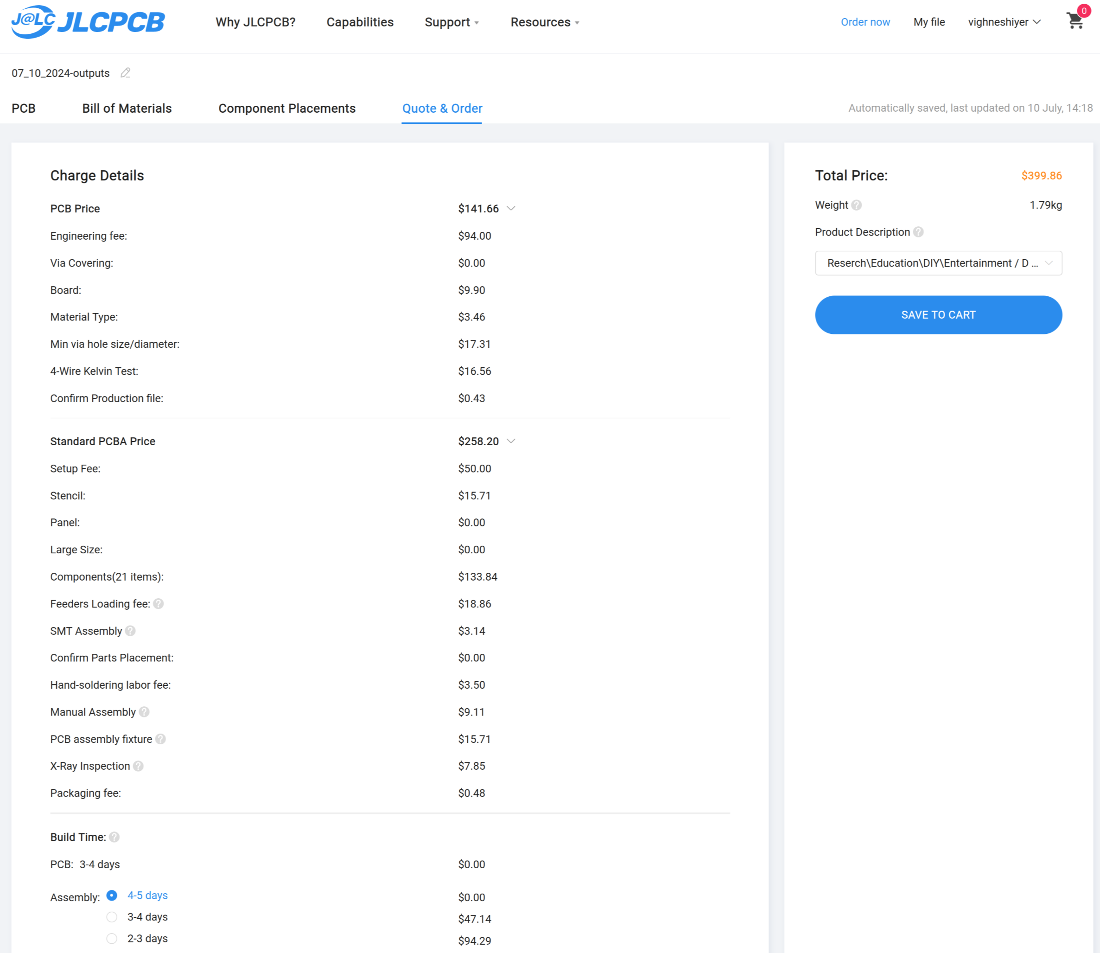
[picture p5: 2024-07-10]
maveric-board/07_10_2024-quote/quote_breakdown.png

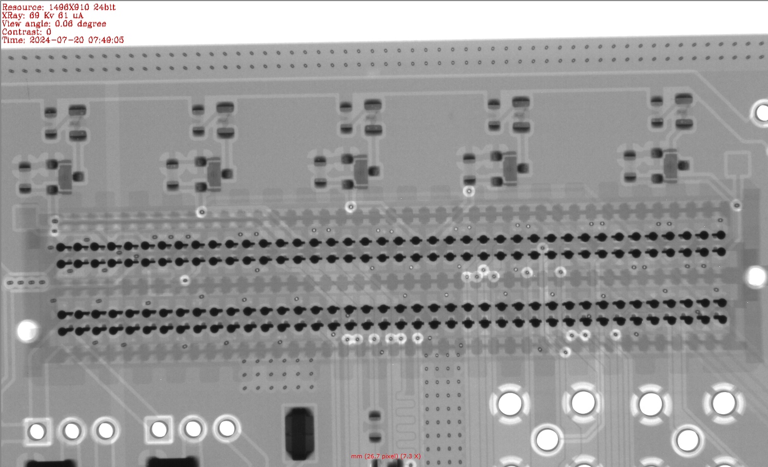
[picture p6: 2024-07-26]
maveric-board/07_22_2024-jlcpcb/xray-1.jpg

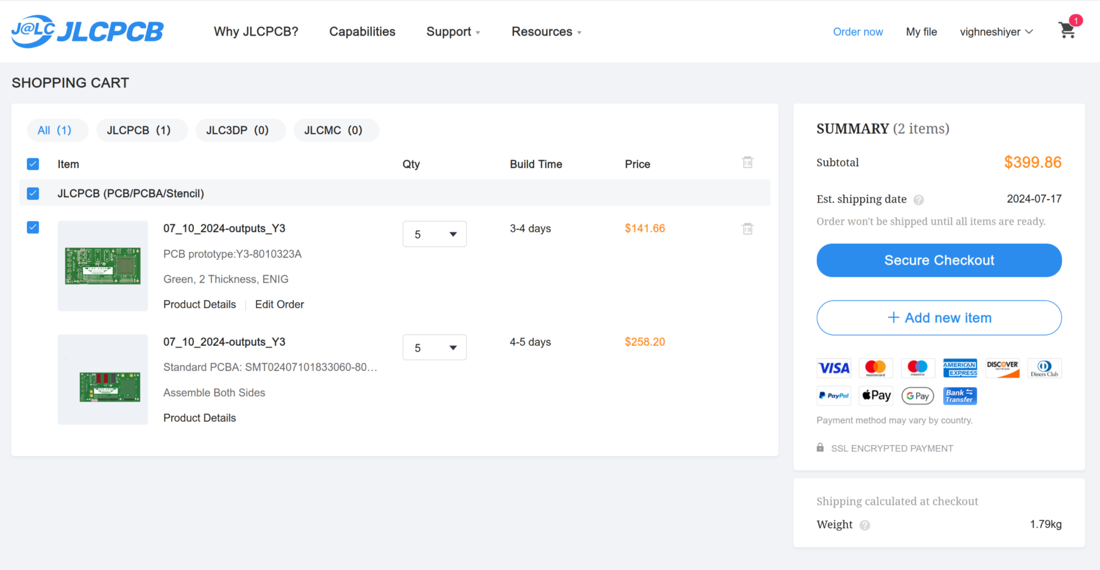
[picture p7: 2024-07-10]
maveric-board/07_10_2024-quote/quote.png

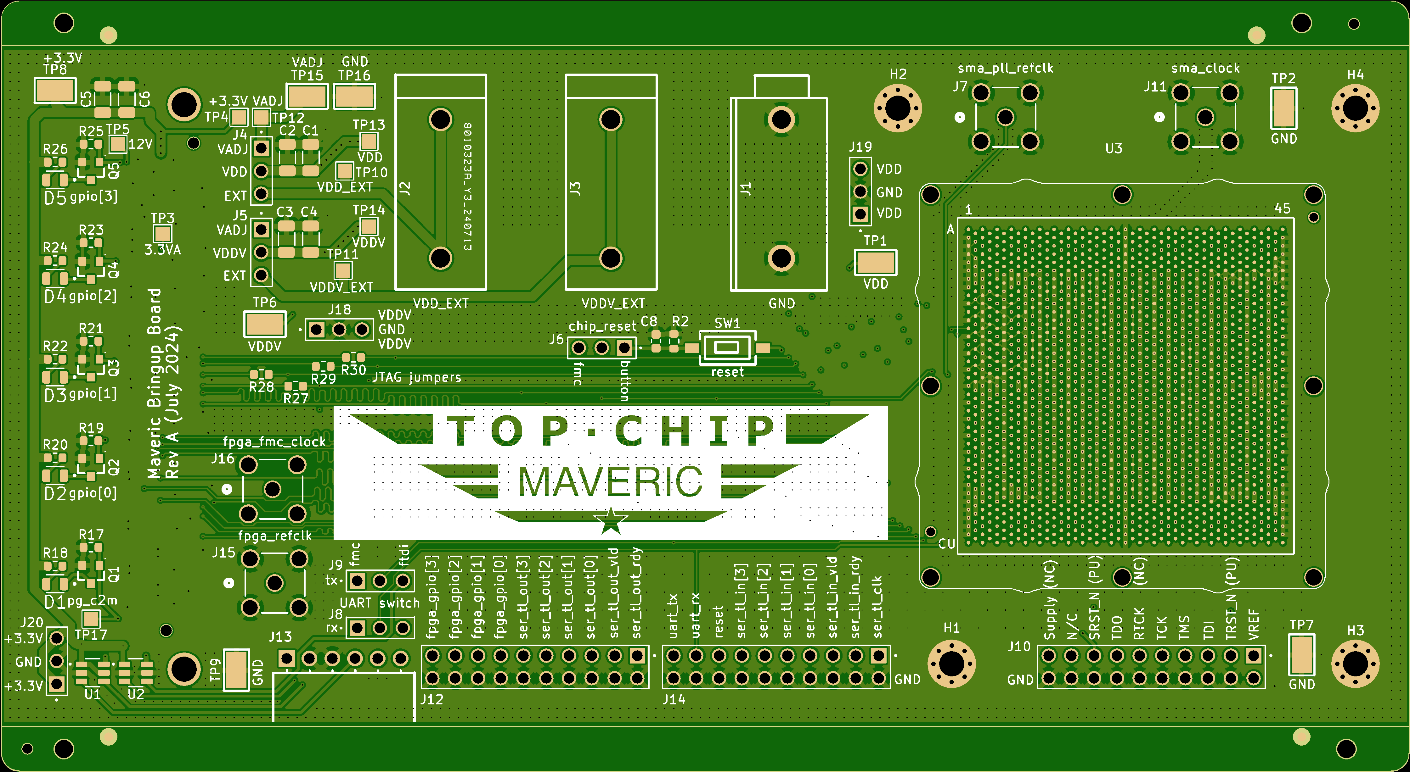
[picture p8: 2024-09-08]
maveric-board-docs/top-production_file.png

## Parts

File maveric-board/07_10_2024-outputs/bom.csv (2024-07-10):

Designator | Comment | Footprint | DNP | LCSC Part Number | Mfr Part #
C1,C2,C3,C4,C5,C6 | 100u | Capacitor_SMD:C_1206_3216Metric |  | C15008 | CL31A107MQHNNNE
C7,C8,C9,C10,C11,C36 | 100n | Capacitor_SMD:C_0603_1608Metric |  | C14663 | CC0603KRX7R9BB104
C12,C13,C14,C15,C16,C17,C18,C19,C20,C21,C22,C23,C24,C25,C26,C27,C28,C29,C30,C31,C32,C33,C34,C35 | 10u | Capacitor_SMD:C_0603_1608Metric |  | C19702 | CL10A106KP8NNNC
D1,D2,D3,D4,D5 | LED | maveric-parts:APT2012LZGCK |  | C5569446 | APT2012LZGCK
J1 | Banana jack (black) | maveric-parts:24.243.2_Black_Banana_Jack |  | C7437322 | 24.243.2
J2,J3 | Banana jack (red) | maveric-parts:24.243.1_Red_Banana_Jack |  | C7437321 | 24.243.1
J4,J5,J6,J8,J9,J18,J19,J20 | 3-pin header | maveric-parts:AMPHENOL_68001-103HLF |  | C598608 | 68001-103HLF
J7,J11,J15,J16 | SMA jack | maveric-parts:5-1814832-2 |  | C482015 | 5-1814832-2
J10,J12,J14 | 20-pin header | maveric-parts:AMPHENOL_67996-220HLF |  | C464650 | 67996-220HLF
J13 | 6-pin female header | maveric-parts:HDR-TH_6P-P2.54-H-F-W5.7 |  | C2833720 | FFH25402-S06B1001K6K
J17 | FMC LPC terminal | maveric-parts:SAMTEC_ASP-134604-01 |  | C2830435 | ASP-134604-01
Q1,Q2,Q3,Q4,Q5 | NMOS | maveric-parts:SOT95P240X120-3N |  | C260950 | DMN2005K-7
R1 | 49.9Ω | Resistor_SMD:R_0603_1608Metric |  | C23185 | 0603WAF499JT5E
R2 | 1k | Resistor_SMD:R_0603_1608Metric |  | C21190 | 0603WAF1001T5E
R3,R4,R5,R6,R7,R8,R9,R10,R11,R12,R13,R14,R15,R16,R27,R28,R29,R30 | 0Ω | Resistor_SMD:R_0603_1608Metric |  | C21189 | 0603WAF0000T5E
R17,R19,R21,R23,R25 | 100kΩ | Resistor_SMD:R_0603_1608Metric |  | C25803 | 0603WAF1003T5E
R18,R20,R22,R24,R26 | 100Ω | Resistor_SMD:R_0603_1608Metric |  | C22775 | 0603WAF1000T5E
R31,R32,R33,R34,R35,R36 | 4.7k | Resistor_SMD:R_0603_1608Metric |  | C23162 | 0603WAF4701T5E
SW1 | Push button switch | maveric-parts:SW-SMD_L6.1-W3.6-LS7.9 |  | C720381 | TS-1007S-AR02516
TP1,TP2,TP6,TP7,TP8,TP9,TP15,TP16 | SMD testpoint | maveric-parts:TESTPOINT-SMD_L3.8-W2.0_RH-5019 |  | C5199800 | RH-5019
TP3,TP4,TP5,TP10,TP11,TP12,TP13,TP14,TP17 | TestPoint_Probe | maveric-parts:TP-60X60_SQ-SMT
U1,U2 | Level shifter | maveric-parts:SN74AVC1T45DBVR |  | C131978 | SN74AVC1T45DBVR
U3 | Testchip socket | maveric-parts:BGA-1733-.92-47.725x47.725 | DNP

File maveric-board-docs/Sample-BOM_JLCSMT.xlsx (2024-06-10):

Comment | Designator | Footprint | JLCPCB Part #（optional）
100uF | C1 | CAP-SMD_L3.5-W2.8 | C16133
15K | R5,R6 | R0603 | C22809
DC-005-20A_C136744 | DC1 | DC-IN-TH_DC-005-20A | C136744
Header-Female-2.54_1x8 | P2,P3 | HDR-TH_8P-P2.54-V | C27438
K2-1102DP-C4SW-04 | SW1 | KEY-TH_4P-L6.0-W6.0-P4.50-LS6.5 | C110153
ATMEGA328P-PU | U1 | DIP-28_L34.6-W7.3-P2.54-LS10.2-BL | C33901
670688000 | USB1 | USB-B-TH_67068-8000 | C114097

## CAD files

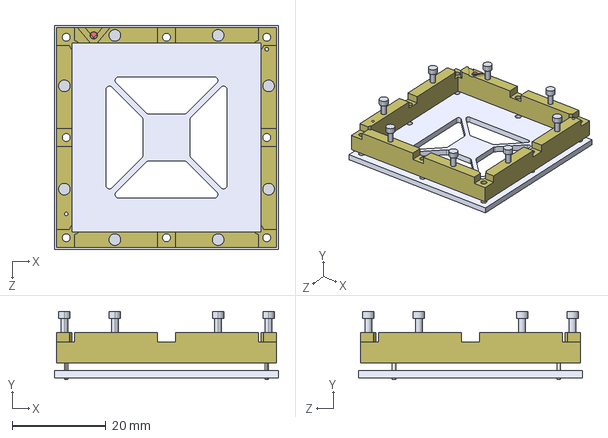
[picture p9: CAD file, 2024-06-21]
maveric-board/3d_models/Asmy_UNI2_for_footprint_3Dmodel.step
47.7 x 14.5 x 47.7 mm
Socket_C22429_Base
P4010.STEP

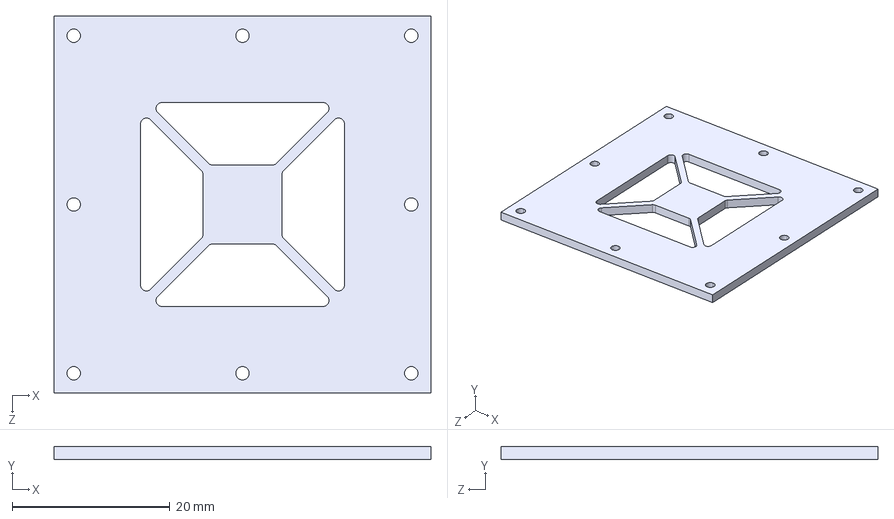
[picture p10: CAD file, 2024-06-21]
maveric-board/3d_models/Asmy_Socket_Ironwood_insulator_bottom_C22429.step
47.7 x 1.59 x 47.7 mm

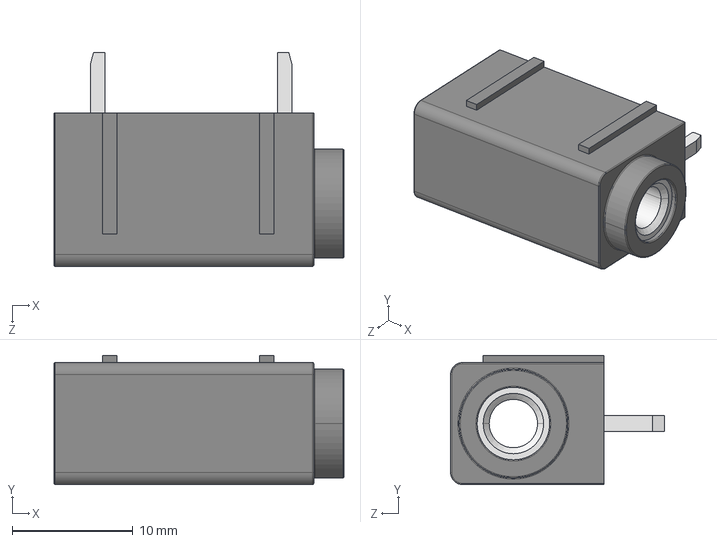
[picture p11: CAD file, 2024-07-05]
maveric-board/3d_models/CONN-TH_24.243.2.step
24.0 x 10.7 x 17.7 mm

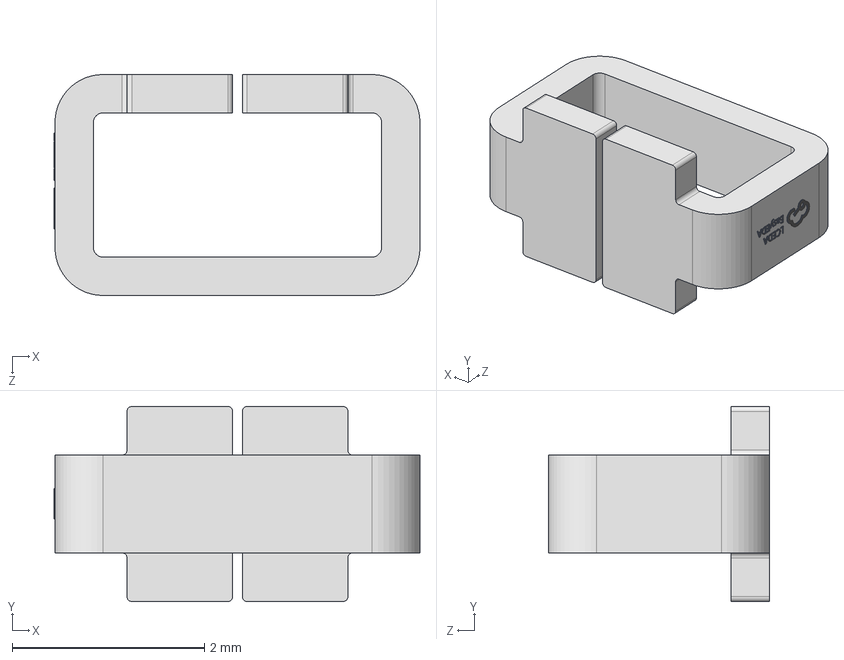
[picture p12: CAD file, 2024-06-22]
maveric-board/3d_models/TESTPOINT-SMD_L3.8-W2.0_RH-5019.step
3.81 x 2.03 x 2.30 mm

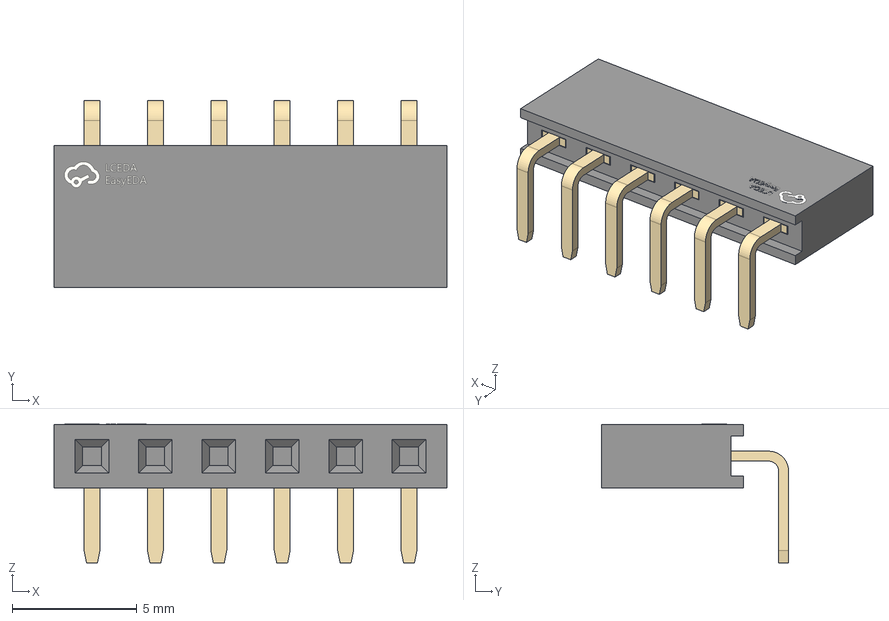
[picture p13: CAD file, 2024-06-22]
maveric-board/3d_models/HDR-TH_6P-P2.54-H-F-W5.7.step
15.7 x 7.50 x 5.55 mm

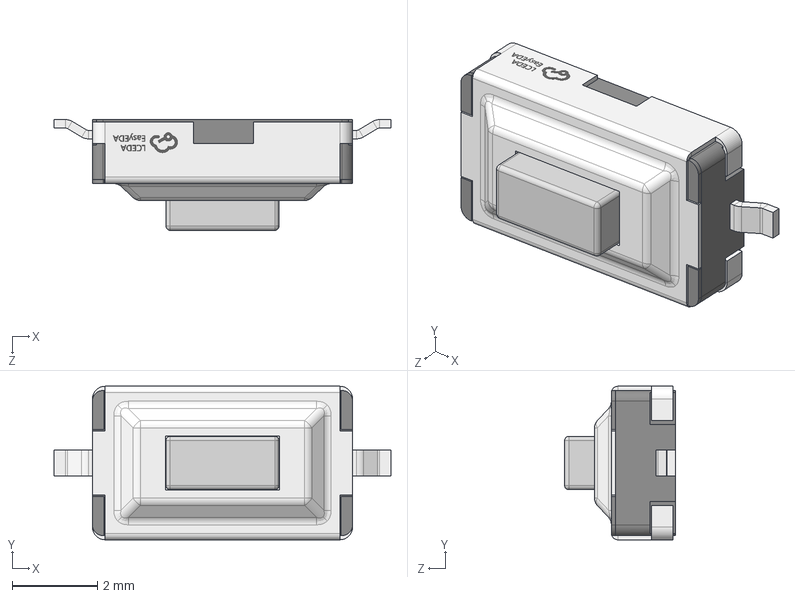
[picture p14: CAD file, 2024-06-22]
maveric-board/3d_models/KEY-SMD_2P-L6.0-W3.6-H2.5-LS8.0.step
7.90 x 3.60 x 2.60 mm

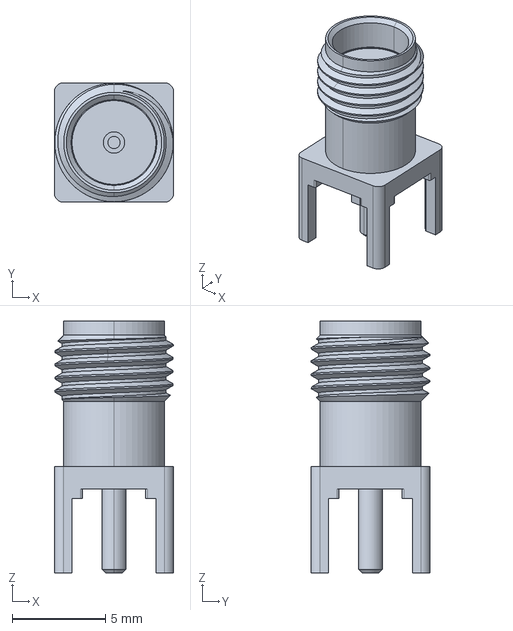
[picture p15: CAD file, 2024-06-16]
maveric-board/3d_models/c-5-1814832-2-c-3d.stp
6.40 x 6.40 x 13.5 mm

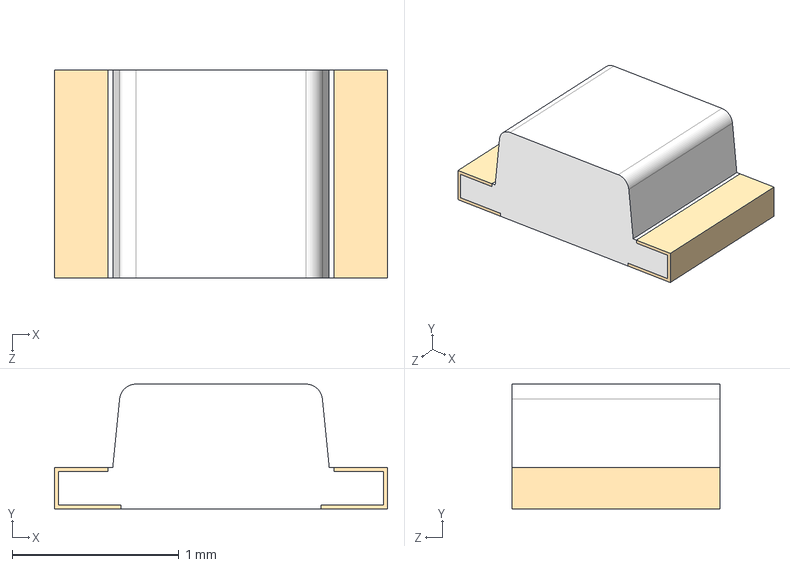
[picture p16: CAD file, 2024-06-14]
maveric-board/3d_models/APT2012LZGCK.step
2.00 x 0.75 x 1.25 mm

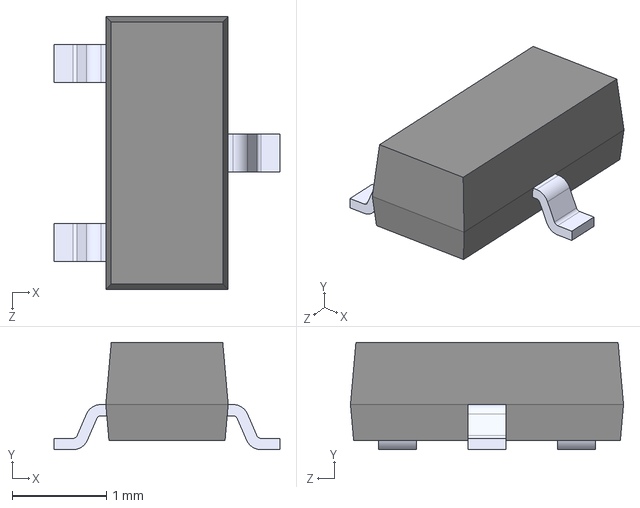
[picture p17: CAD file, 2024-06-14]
maveric-board/3d_models/DMN2005K-7.step
2.40 x 1.14 x 2.90 mm

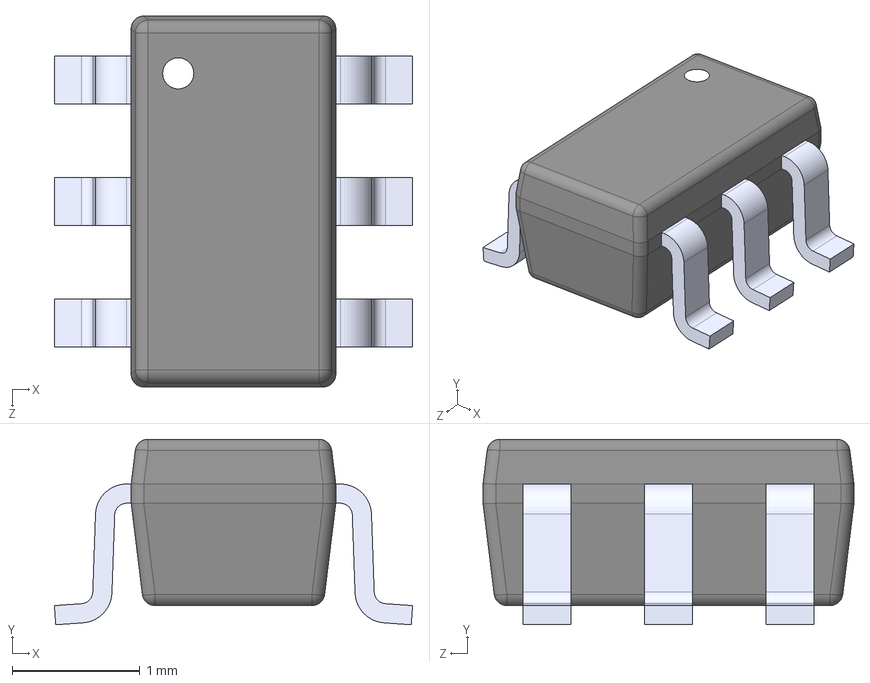
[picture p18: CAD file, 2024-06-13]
maveric-board/3d_models/SN74AVC1T45DBVR.step
2.80 x 1.45 x 2.90 mm

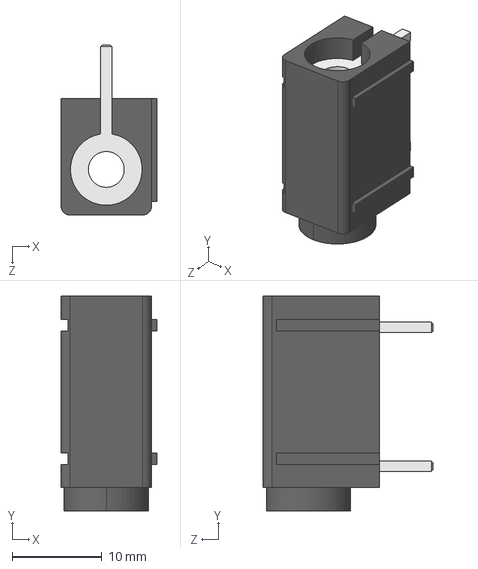
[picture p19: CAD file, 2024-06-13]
maveric-board/3d_models/24.243.2.stp
10.7 x 24.0 x 19.0 mm

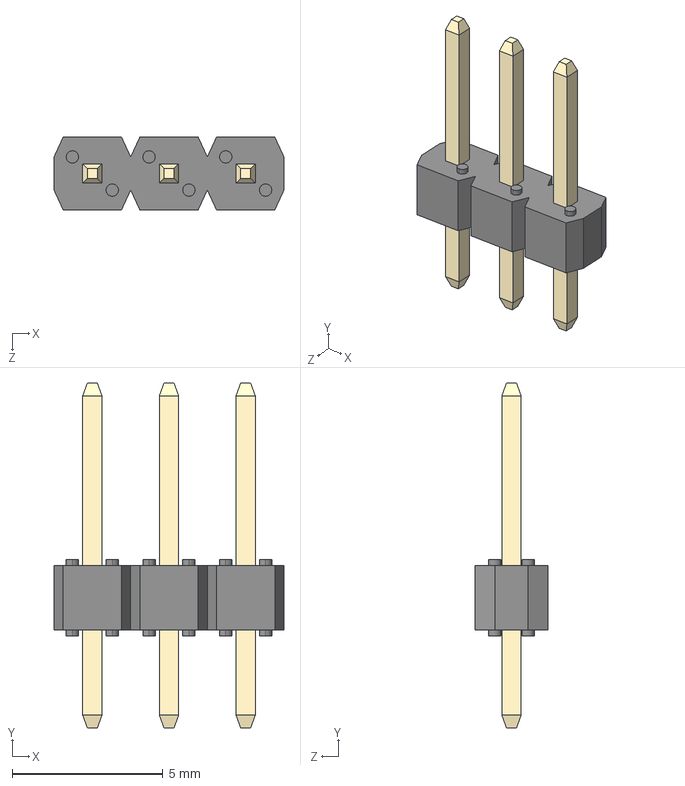
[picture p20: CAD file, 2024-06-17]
maveric-board/3d_models/68001-103HLF.step
7.62 x 11.4 x 2.41 mm
68000 gold body_03
pin^68000 Gold x 3

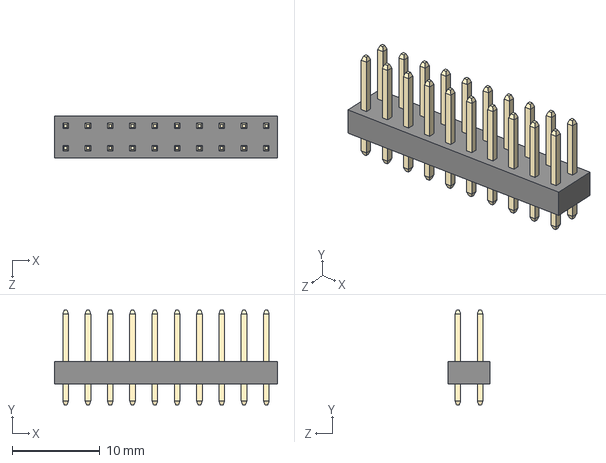
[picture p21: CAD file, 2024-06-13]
maveric-board/3d_models/67996-220HLF.step
25.4 x 10.8 x 4.83 mm

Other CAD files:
maveric-board/3d_models/AUDIO-TH_24.243.1.step
maveric-board/3d_models/24.243.1.stp

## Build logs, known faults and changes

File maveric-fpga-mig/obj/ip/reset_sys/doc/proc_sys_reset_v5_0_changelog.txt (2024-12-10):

2023.1:
 * Version 5.0 (Rev. 13)
 * No changes

2022.2.2:
 * Version 5.0 (Rev. 13)
 * No changes

2022.2.1:
 * Version 5.0 (Rev. 13)
 * No changes

2022.2:
 * Version 5.0 (Rev. 13)
 * No changes

2022.1.2:
 * Version 5.0 (Rev. 13)
 * No changes

2022.1.1:
 * Version 5.0 (Rev. 13)
 * No changes

2022.1:
 * Version 5.0 (Rev. 13)
 * No changes

2021.2.2:
 * Version 5.0 (Rev. 13)
 * No changes

2021.2.1:
 * Version 5.0 (Rev. 13)
 * No changes

2021.2:
 * Version 5.0 (Rev. 13)
 * No changes

2021.1.1:
 * Version 5.0 (Rev. 13)
 * No changes

2021.1:
 * Version 5.0 (Rev. 13)
 * No changes

2020.3:
 * Version 5.0 (Rev. 13)
 * No changes

2020.2.2:
 * Version 5.0 (Rev. 13)
 * No changes

2020.2.1:
 * Version 5.0 (Rev. 13)
 * No changes

2020.2:
 * Version 5.0 (Rev. 13)
 * No changes

2020.1.1:
 * Version 5.0 (Rev. 13)
 * No changes

2020.1:
 * Version 5.0 (Rev. 13)
 * No changes

2019.2.2:
 * Version 5.0 (Rev. 13)
 * No changes

2019.2.1:
 * Version 5.0 (Rev. 13)
 * No changes

2019.2:
 * Version 5.0 (Rev. 13)
 * No changes

2019.1.3:
 * Version 5.0 (Rev. 13)
 * No changes

2019.1.2:
 * Version 5.0 (Rev. 13)
 * No changes

2019.1.1:
 * Version 5.0 (Rev. 13)
 * No changes

2019.1:
 * Version 5.0 (Rev. 13)
 * No changes

2018.3.1:
 * Version 5.0 (Rev. 13)
 * No changes

2018.3:
 * Version 5.0 (Rev. 13)
 * General: removed equivalent_register_removal

2018.2:
 * Version 5.0 (Rev. 12)
 * No changes

2018.1:
 * Version 5.0 (Rev. 12)
 * No changes

2017.4:
 * Version 5.0 (Rev. 12)
 * No changes

2017.3:
 * Version 5.0 (Rev. 12)
 * General: Reset outputs initialized with a POR value

2017.2:
 * Version 5.0 (Rev. 11)
 * No changes

2017.1:
 * Version 5.0 (Rev. 11)
 * General: Board flow related updates, no functional changes

2016.4:
 * Version 5.0 (Rev. 10)
 * No changes

2016.3:
 * Version 5.0 (Rev. 10)
 * General: Source HDL files are concatenated into a single file to speed up synthesis and simulation. No changes required by the user

2016.2:
 * Version 5.0 (Rev. 9)
 * No changes

2016.1:
 * Version 5.0 (Rev. 9)
 * Updated bd.tcl post config procedure. No functional change.

2015.4.2:
 * Version 5.0 (Rev. 8)
 * No changes

2015.4.1:
 * Version 5.0 (Rev. 8)
 * No changes

2015.4:
 * Version 5.0 (Rev. 8)
 * No changes

2015.3:
 * Version 5.0 (Rev. 8)
 * Renamed the internal module to avoid conflict with VHDL2008 keyword, no functional change.
 * IP revision number added to HDL module, library, and include file names, to support designs with both locked and upgraded IP instances
 * Revision change in one or more subcores

2015.2.1:
 * Version 5.0 (Rev. 7)
 * No changes

2015.2:
 * Version 5.0 (Rev. 7)
 * No changes

2015.1:
 * Version 5.0 (Rev. 7)
 * Enabled out-of-context clock frequency setting by adding FREQ_HZ parameter to slowest_sync_clk
 * Supported devices and production status are now determined automatically, to simplify support for future devices

2014.4.1:
 * Version 5.0 (Rev. 6)
 * No changes

2014.4:
 * Version 5.0 (Rev. 6)
 * No changes

2014.3:
 * Version 5.0 (Rev. 6)
 * Modified to use new sub-cores in place of proc_common,no functional changes
 * Updated synchronizers for clock domain crossing to reduce Mean Time Between Failures (MTBF) from metastability
 * Updated core to use utils.tcl, needed for board flow from common location

2014.2:
 * Version 5.0 (Rev. 5)
 * Enhanced support for IP Integrator
 * Board flow related updates, no functional changes

2014.1:
 * Version 5.0 (Rev. 4)
 * Internal device family name change, no functional changes

2013.4:
 * Version 5.0 (Rev. 3)
 * Added exdes.xdc file
 * Changed the associated resets for slowest_sync_clk
 * Kintex UltraScale Pre-Production support

2013.3:
 * Version 5.0 (Rev. 2)
 * Changed board flow specific parameter name as per new requirements
 * Added example design and demonstration testbench
 * Reduced warnings in synthesis and simulation
 * Enhanced support for IP Integrator
 * Added support for Cadence IES and Synopsys VCS simulators
 * Updated synchronizers for clock domain crossing to reduce Mean Time Between Failures (MTBF) from metastability
 * Support for 7-series devices at Production status

2013.2:
 * Version 5.0 (Rev. 1)
 * Added BETA support for future devices.
 * No other RTL updates

2013.1:
 * Version 5.0
 * Updated version for 2013.1
 * Updated bd.tcl for board flow
 * No other RTL updates

(c) Copyright 2013 - 2023 Xilinx, Inc. All rights reserved.

This file contains confidential and proprietary information
of Xilinx, Inc. and is protected under U.S. and
international copyright and other intellectual property
laws.

DISCLAIMER
This disclaimer is not a license and does not grant any
rights to the materials distributed herewith. Except as
otherwise provided in a valid license issued to you by
Xilinx, and to the maximum extent permitted by applicable
law: (1) THESE MATERIALS ARE MADE AVAILABLE "AS IS" AND
WITH ALL FAULTS, AND XILINX HEREBY DISCLAIMS ALL WARRANTIES
AND CONDITIONS, EXPRESS, IMPLIED, OR STATUTORY, INCLUDING
BUT NOT LIMITED TO WARRANTIES OF MERCHANTABILITY, NON-
INFRINGEMENT, OR FITNESS FOR ANY PARTICULAR PURPOSE; and
(2) Xilinx shall not be liable (whether in contract or tort,
including negligence, or under any other theory of
liability) for any loss or damage of any kind or nature
related to, arising under or in connection with these
materials, including for any direct, or any indirect,
special, incidental, or consequential loss or damage
(including loss of data, profits, goodwill, or any type of
loss or damage suffered as a result of any action brought
by a third party) even if such damage or loss was
reasonably foreseeable or Xilinx had been advised of the
possibility of the same.

CRITICAL APPLICATIONS
Xilinx products are not designed or intended to be fail-
safe, or for use in any application requiring fail-safe
performance, such as life-support or safety devices or
systems, Class III medical devices, nuclear facilities,
applications related to the deployment of airbags, or any
other applications that could lead to death, personal
injury, or severe property or environmental damage
(individually and collectively, "Critical
Applications"). Customer assumes the sole risk and
liability of any use of Xilinx products in Critical
Applications, subject only to applicable laws and
regulations governing limitations on product liability.

THIS COPYRIGHT NOTICE AND DISCLAIMER MUST BE RETAINED AS
PART OF THIS FILE AT ALL TIMES.

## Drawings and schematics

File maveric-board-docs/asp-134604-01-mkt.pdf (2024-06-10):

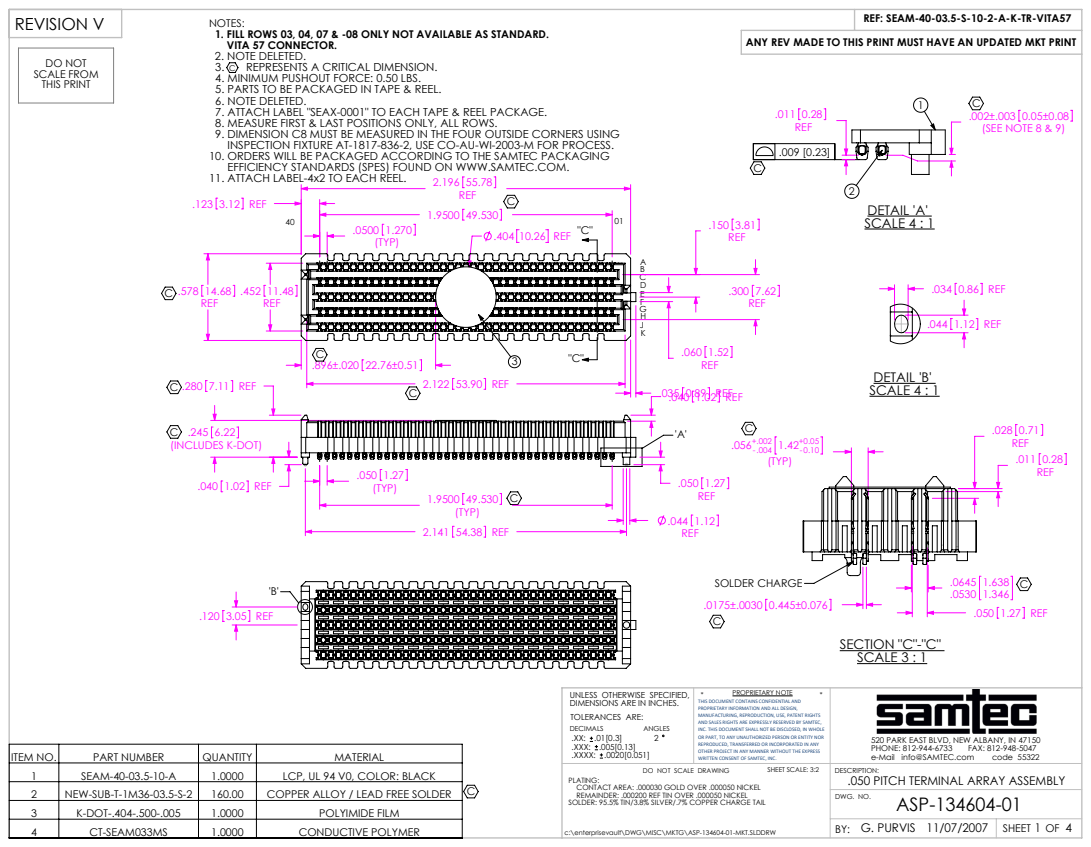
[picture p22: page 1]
DO NOT SCALE FROM THIS PRINT; (INCLUDES K-DOT); .035 0.89 REF; 2.122 53.90 REF; .404 10.26 REF; .002±.003 0.05±0.08 (SEE NOTE 8 & 9); DETAIL 'A' SCALE 4 : 1; SEAM-40-03.5-10-A; LCP, UL 94 V0, COLOR: BLACK; CT-SEAM033MS; CONDUCTIVE POLYMER; DETAIL 'B' SCALE 4 : 1; REF .056-.004; SECTION "C"-"C" SCALE 3 : 1; SOLDER CHARGE; SHEET OF; DO NOT SCALE DRAWING; DESCRIPTION:; G. PURVIS 11/07/2007; REVISION V

NOTES:
1. FILL ROWS 03, 04, 07 & -08 ONLY NOT AVAILABLE AS STANDARD.
VITA 57 CONNECTOR.
2. NOTE DELETED.
3. REPRESENTS A CRITICAL DIMENSION.
4. MINIMUM PUSHOUT FORCE: 0.50 LBS.
5. PARTS TO BE PACKAGED IN TAPE & REEL.
6. NOTE DELETED.
7. ATTACH LABEL "SEAX-0001" TO EACH TAPE & REEL PACKAGE.
8. MEASURE FIRST & LAST POSITIONS ONLY, ALL ROWS.
9. DIMENSION C8 MUST BE MEASURED IN THE FOUR OUTSIDE CORNERS USING
INSPECTION FIXTURE AT-1817-836-2, USE CO-AU-WI-2003-M FOR PROCESS.
10. ORDERS WILL BE PACKAGED ACCORDING TO THE SAMTEC PACKAGING
EFFICIENCY STANDARDS (SPES) FOUND ON WWW.SAMTEC.COM.
11. ATTACH LABEL-4x2 TO EACH REEL.

REF: SEAM-40-03.5-S-10-2-A-K-TR-VITA57

ANY REV MADE TO THIS PRINT MUST HAVE AN UPDATED MKT PRINT

UNLESS OTHERWISE SPECIFIED, DIMENSIONS ARE IN INCHES. TOLERANCES ARE: DECIMALS ANGLES .XX: .01[0.3] 2 .XXX: .005[0.13] .XXXX: .0020[0.051] | * PROPRIETARY NOTE * THIS DOCUMENT CONTAINS CONFIDENTIAL AND PROPRIETARY INFORMATION AND ALL DESIGN, MANUFACTURING, REPRODUCTION, USE, PATENT RIGHTS AND SALES RIGHTS ARE EXPRESSLY RESERVED BY SAMTEC, INC. THIS DOCUMENT SHALL NOT BE DISCLOSED, IN WHOLE OR PART, TO ANY UNAUTHORIZED PERSON OR ENTITY NOR REPRODUCED, TRANSFERRED OR INCORPORATED IN ANY OTHER PROJECT IN ANY MANNER WITHOUT THE EXPRESS WRITTEN CONSENT OF SAMTEC, INC. | 520 PARK EAST BLVD, NEW ALBANY, IN 47150 PHONE: 812-944-6733 FAX: 812-948-5047 e-Mail info@SAMTEC.com code 55322

ITEM NO. | PART NUMBER | QUANTITY | MATERIAL

SHEET SCALE: 3:2
ASP-134604-01 DWG. NO.

.050 PITCH TERMINAL ARRAY ASSEMBLY

PLATING:
CONTACT AREA: .000030 GOLD OVER .000050 NICKEL
REMAINDER: .000200 REF TIN OVER .000050 NICKEL
SOLDER: 95.5% TIN/3.8% SILVER/.7% COPPER CHARGE TAIL

2 | NEW-SUB-T-1M36-03.5-S-2 | 160.00 | COPPER ALLOY / LEAD FREE SOLDER
3 | K-DOT-.404-.500-.005 | 1.0000 | POLYIMIDE FILM

c:\enterprisevault\DWG\MISC\MKTG\ASP-134604-01-MKT.SLDDRW

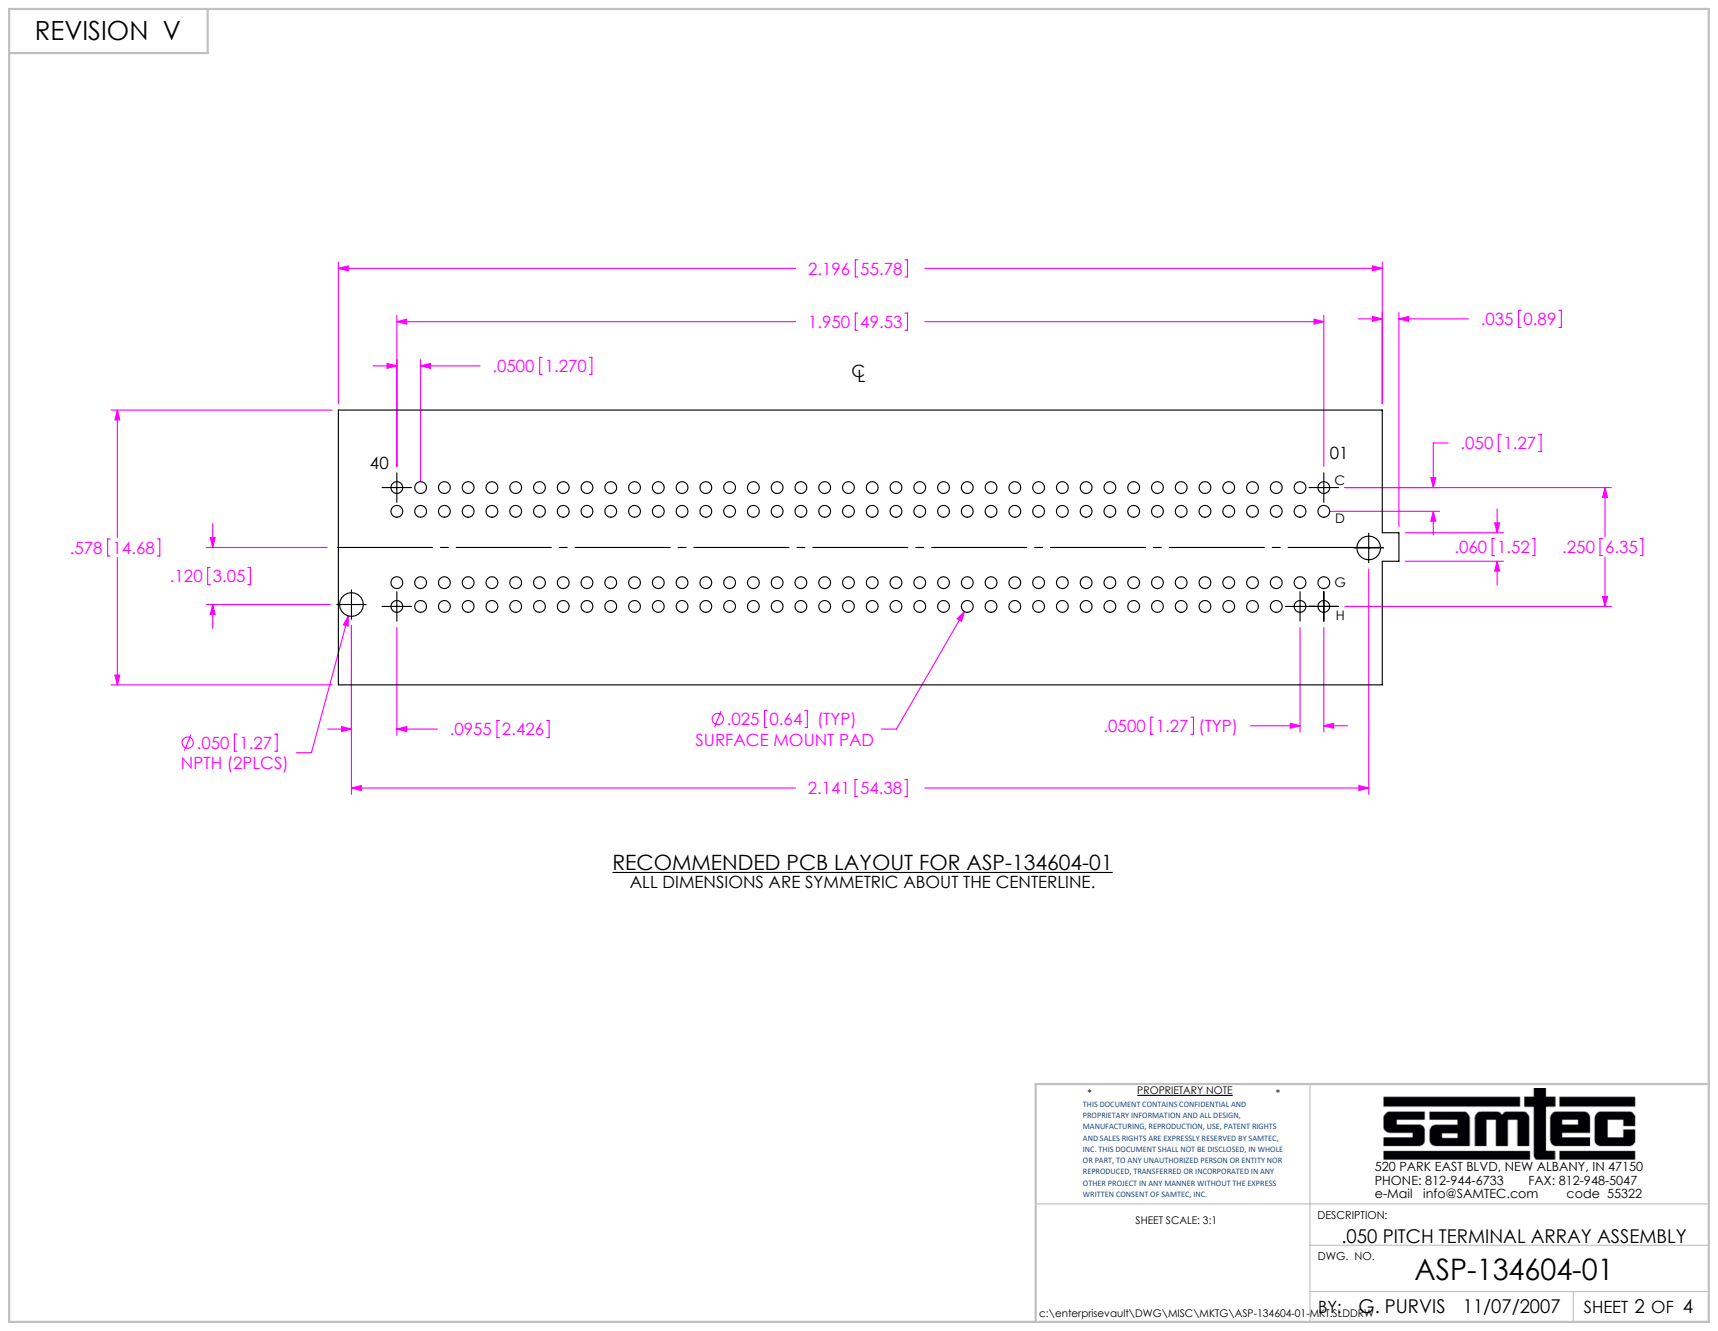
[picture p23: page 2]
.0500 1.27 (TYP); .050 1.27 NPTH (2PLCS); G. PURVIS 11/07/2007

.025 0.64 (TYP)
SURFACE MOUNT PAD

RECOMMENDED PCB LAYOUT FOR ASP-134604-01
ALL DIMENSIONS ARE SYMMETRIC ABOUT THE CENTERLINE.

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

SHEET SCALE: 3:1 | DESCRIPTION: .050 PITCH TERMINAL ARRAY ASSEMBLY

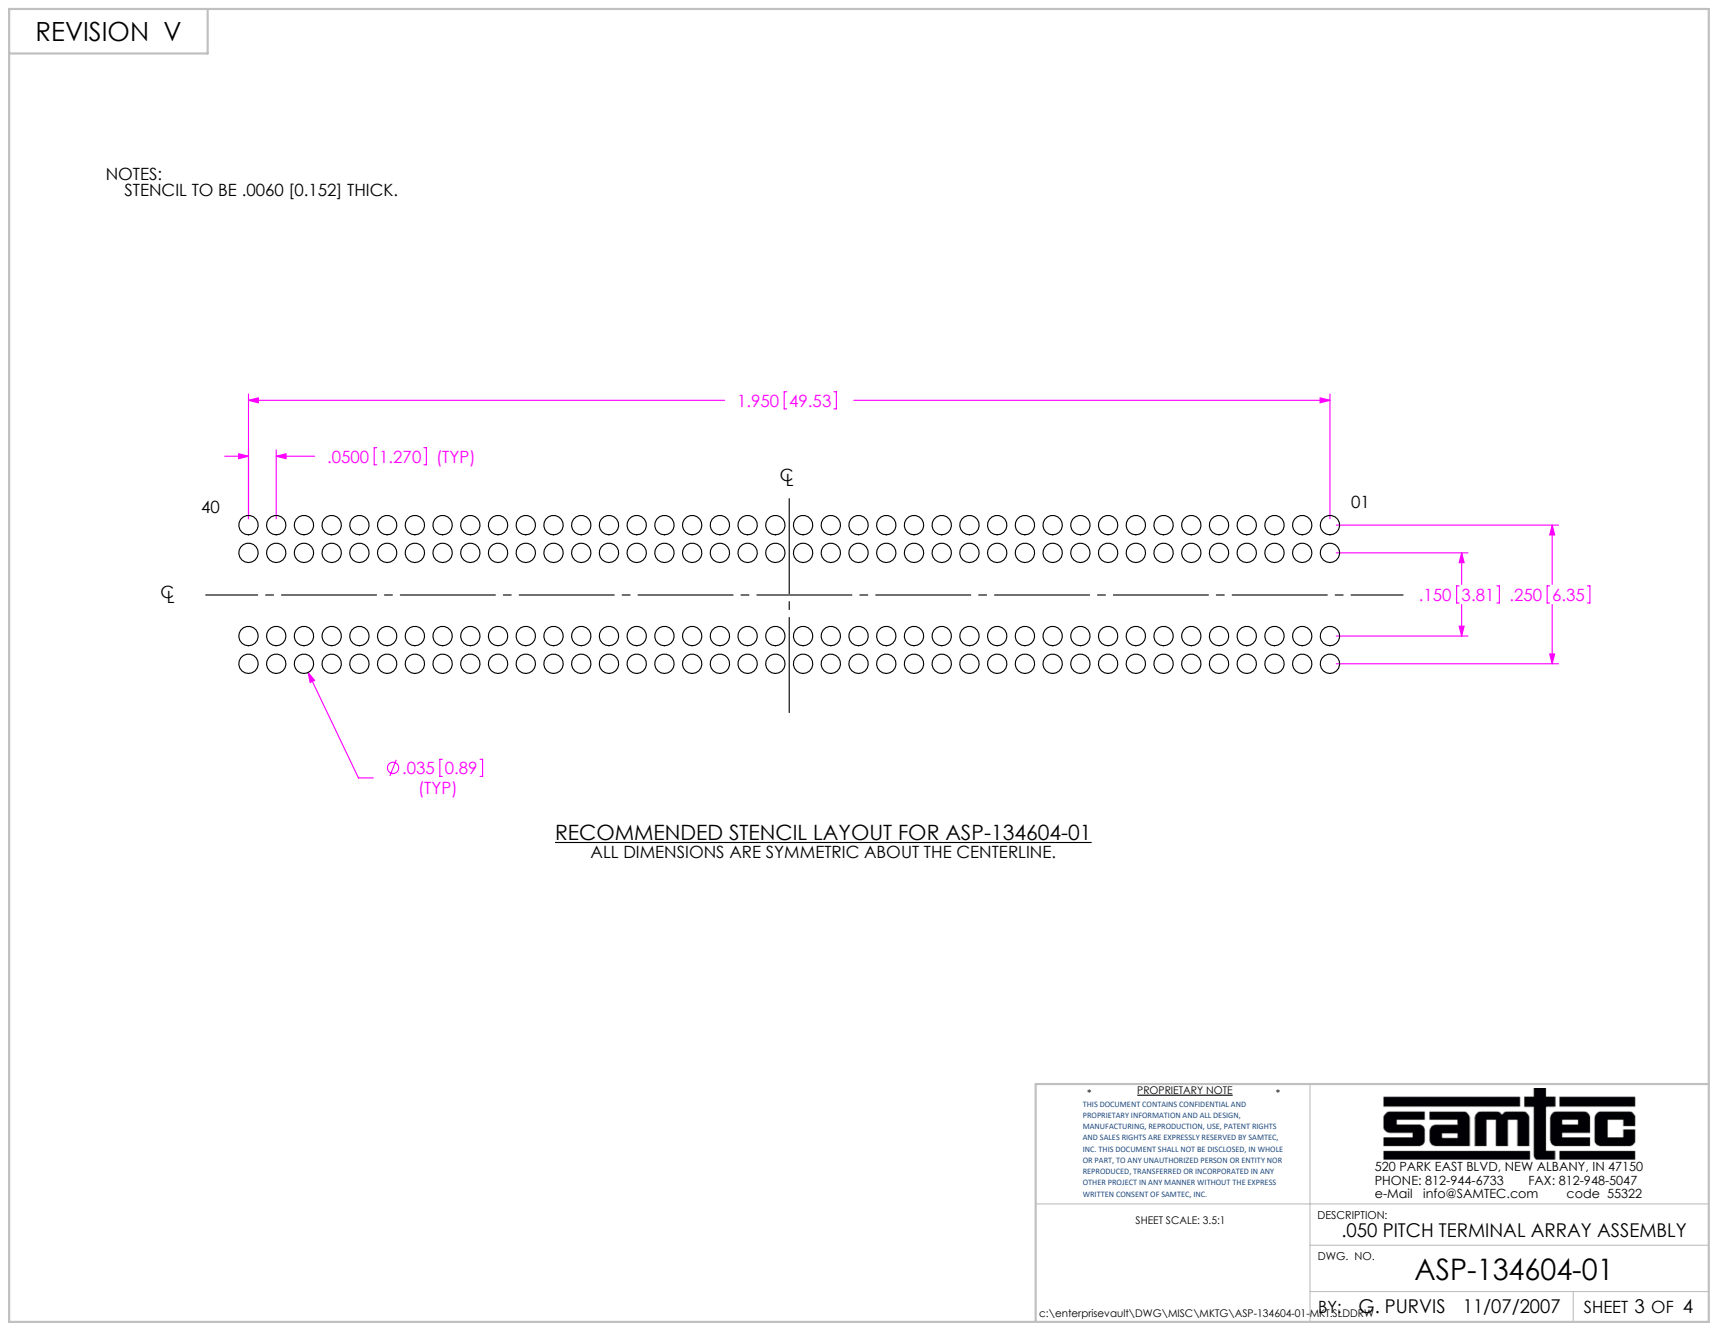
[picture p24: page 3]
.0500 1.270 (TYP); G. PURVIS 11/07/2007

NOTES:
STENCIL TO BE .0060 [0.152] THICK.

RECOMMENDED STENCIL LAYOUT FOR ASP-134604-01
ALL DIMENSIONS ARE SYMMETRIC ABOUT THE CENTERLINE.

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

SHEET SCALE: 3.5:1 | DESCRIPTION: .050 PITCH TERMINAL ARRAY ASSEMBLY

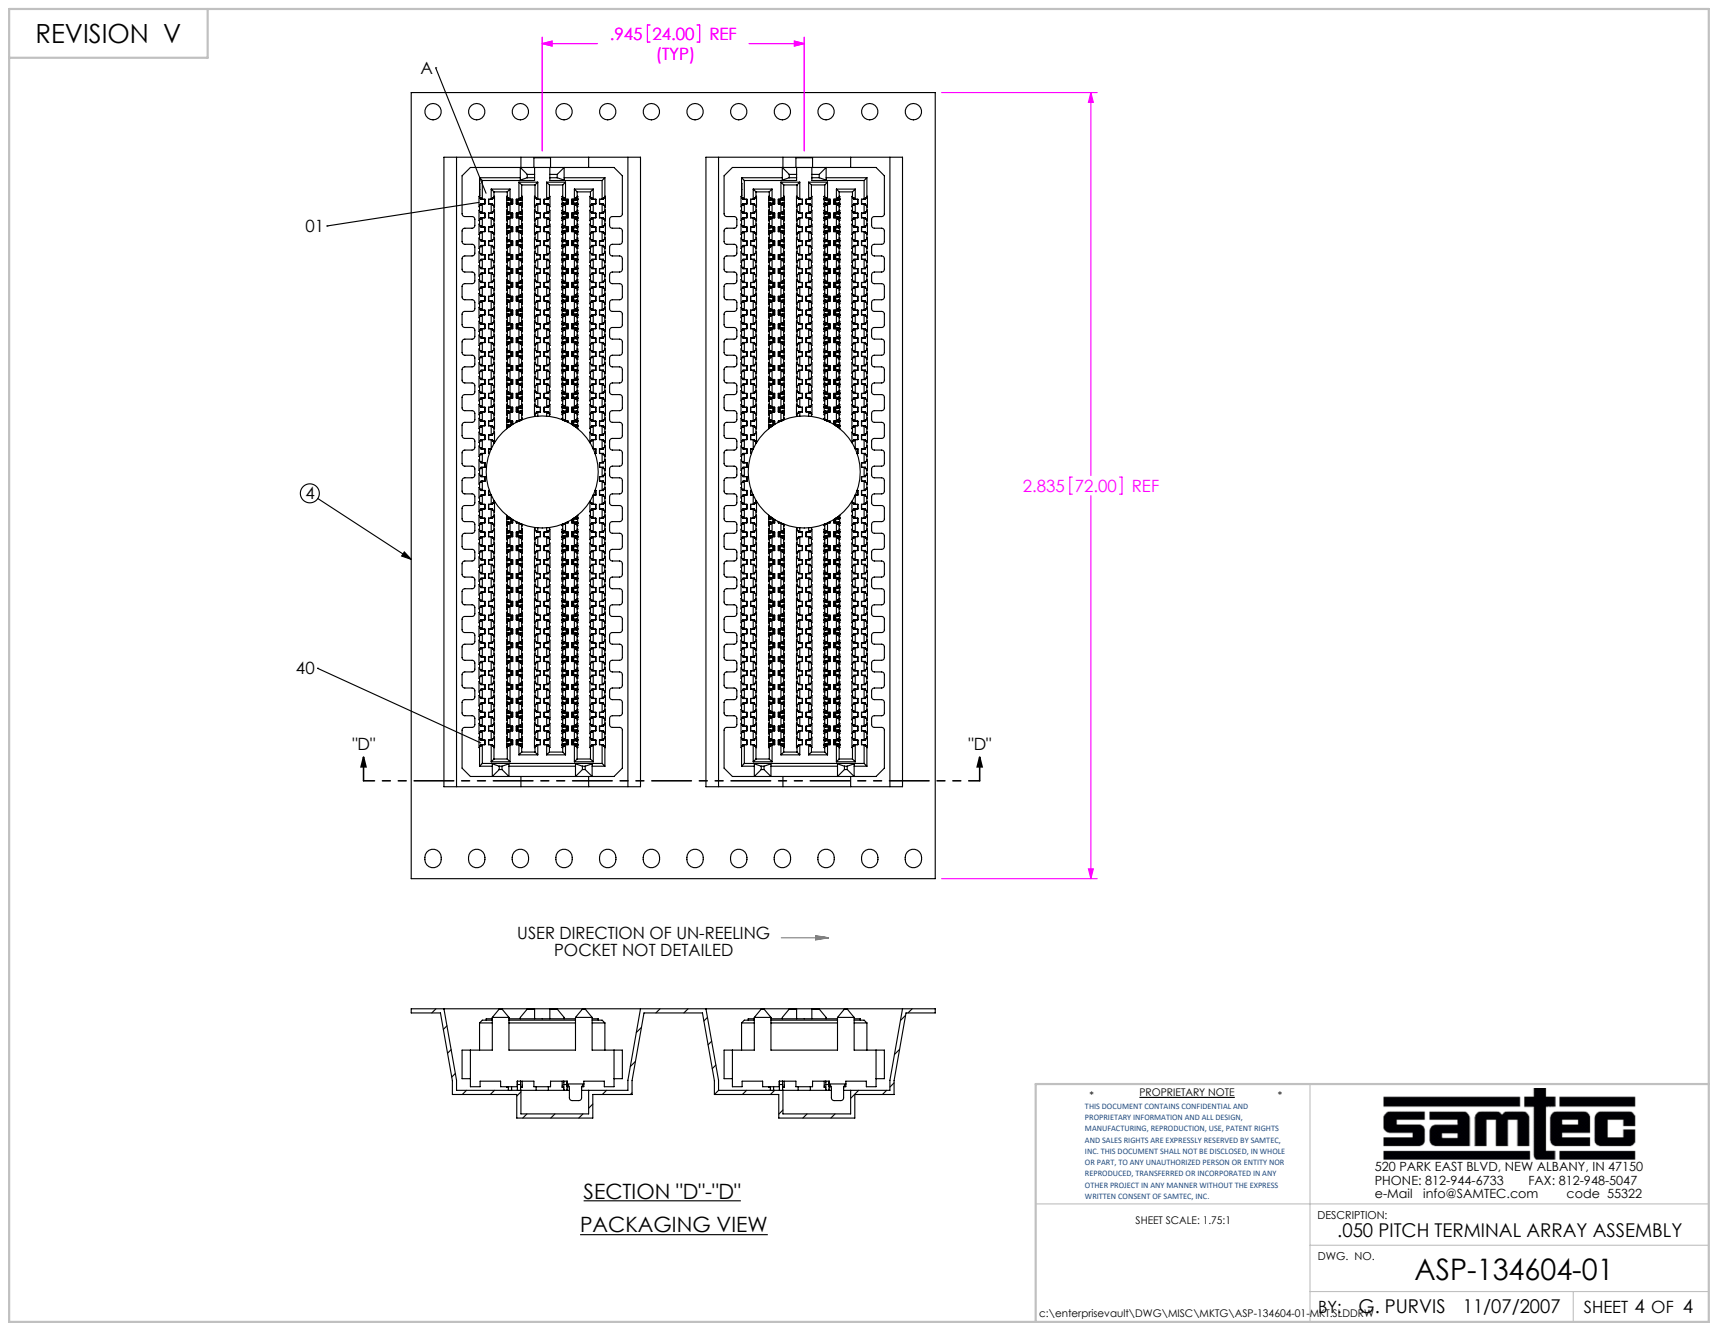
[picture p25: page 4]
SECTION "D"-"D" PACKAGING VIEW; G. PURVIS 11/07/2007

USER DIRECTION OF UN-REELING
POCKET NOT DETAILED
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

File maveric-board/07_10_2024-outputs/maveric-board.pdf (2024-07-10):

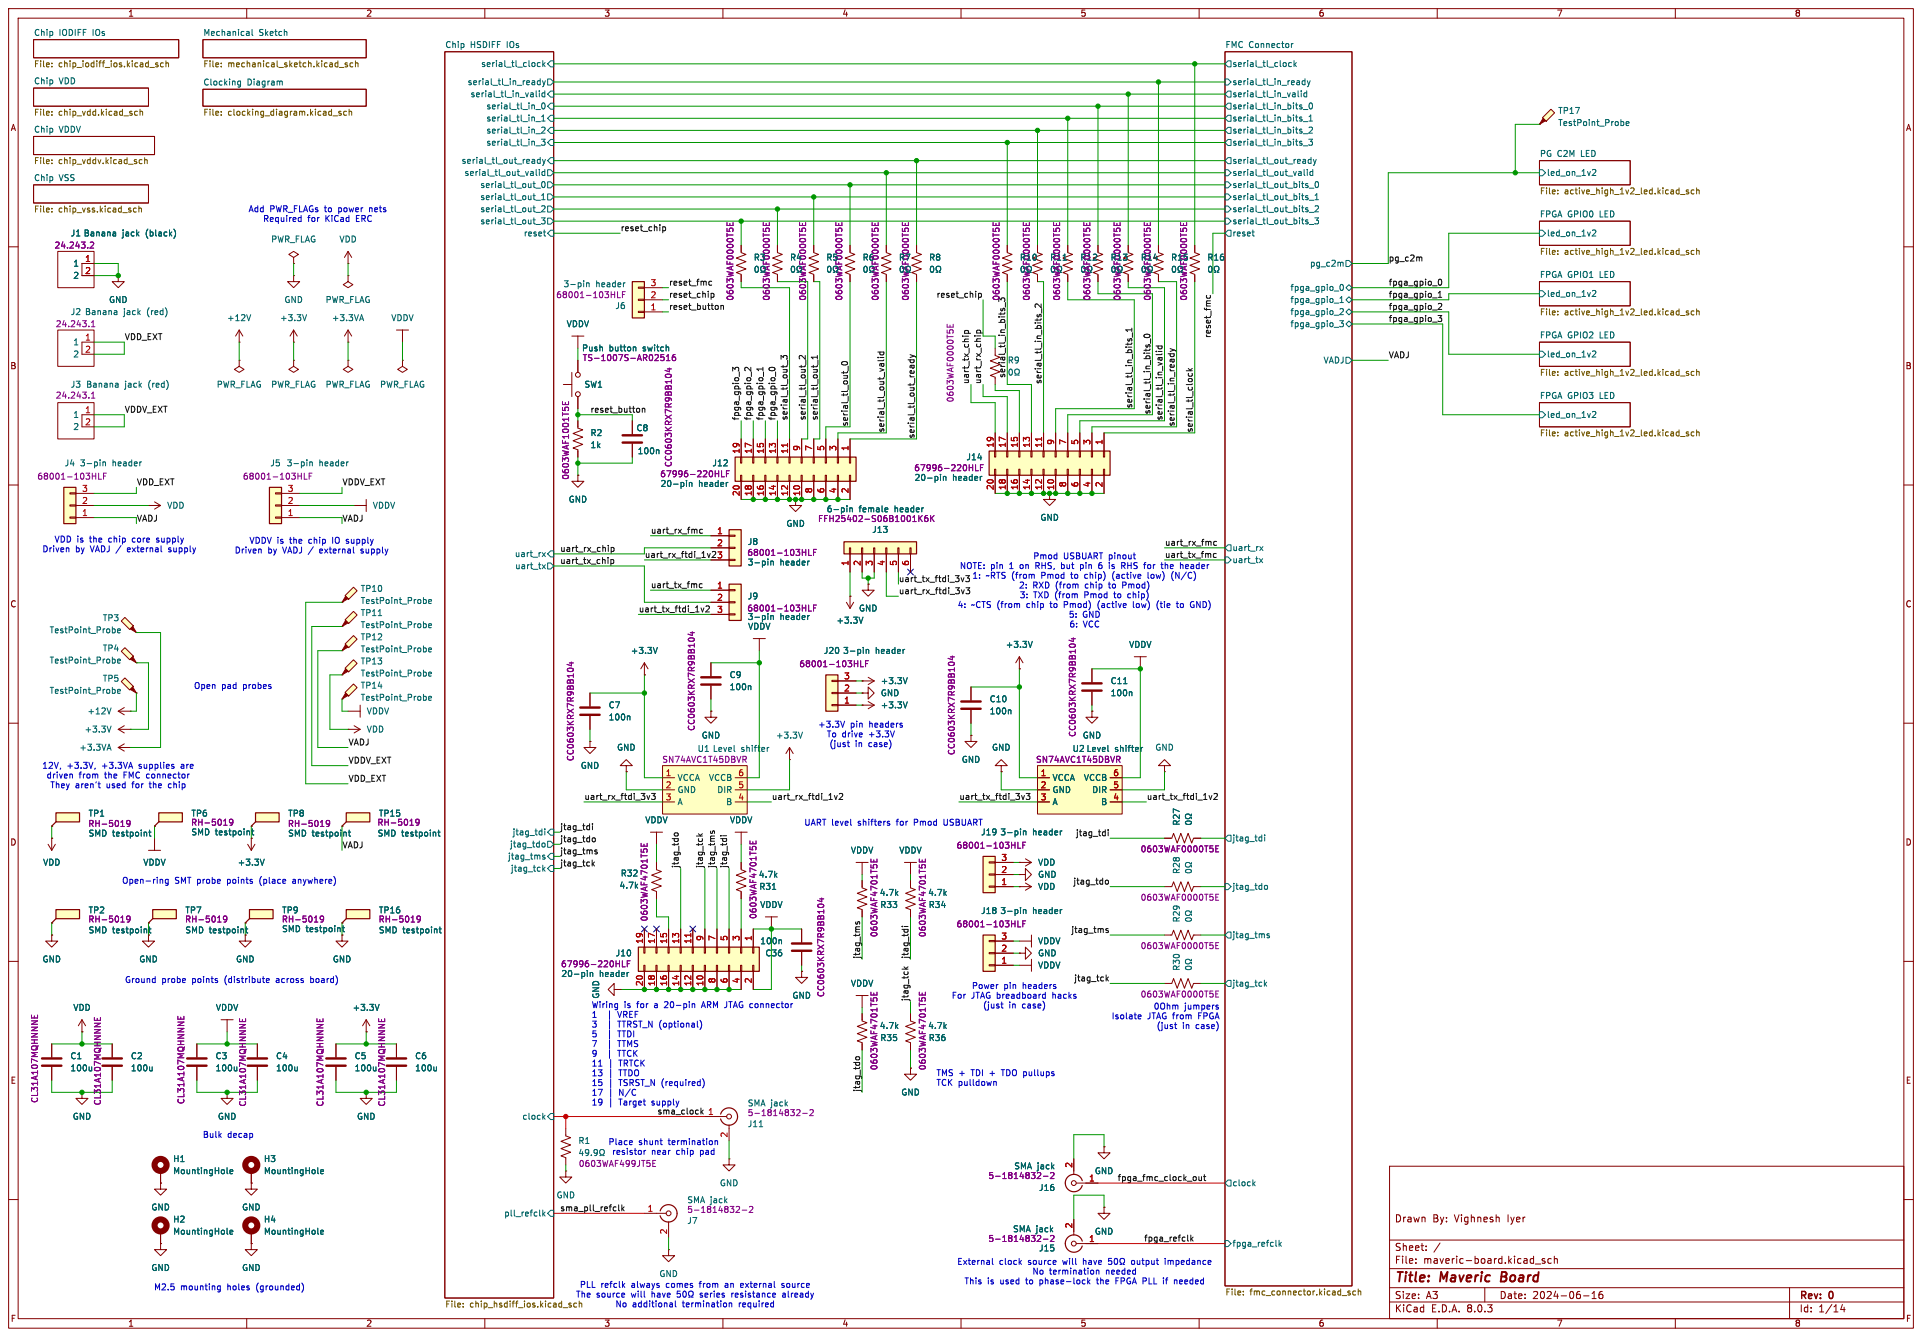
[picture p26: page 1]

File: active_high_1v2_led.kicad_sch Chip IODIFF IOs File: chip_iodiff_ios.kicad_sch Chip VDD

Add PWR_FLAGs to power nets Required for KiCad ERC

Pmod USBUART pinout NOTE: pin 1 on RHS, but pin 6 is RHS for the header 1: ~RTS (from Pmod to chip) (active low) (N/C) 2: RXD (from chip to Pmod) 3: TXD (from Pmod to chip) 4: ~CTS (from chip to Pmod) (active low) (tie to GND) 5: GND

+3.3V pin headers To drive +3.3V

4 DIR 5 VCCB 6 U1 Level shifter SN74AVC1T45DBVR

4 DIR 5 VCCB 6 U2 Level shifter SN74AVC1T45DBVR

TP9 SMD testpoint RH-5019 TP8 SMD testpoint RH-5019 GND

TP2 SMD testpoint RH-5019 VDD

Isolate JTAG from FPGA

H1 MountingHole H2 MountingHole GND GND

File: maveric-board.kicad_sch Sheet: / Drawn By: Vighnesh Iyer

Id: 1/14 Title: Maveric Board

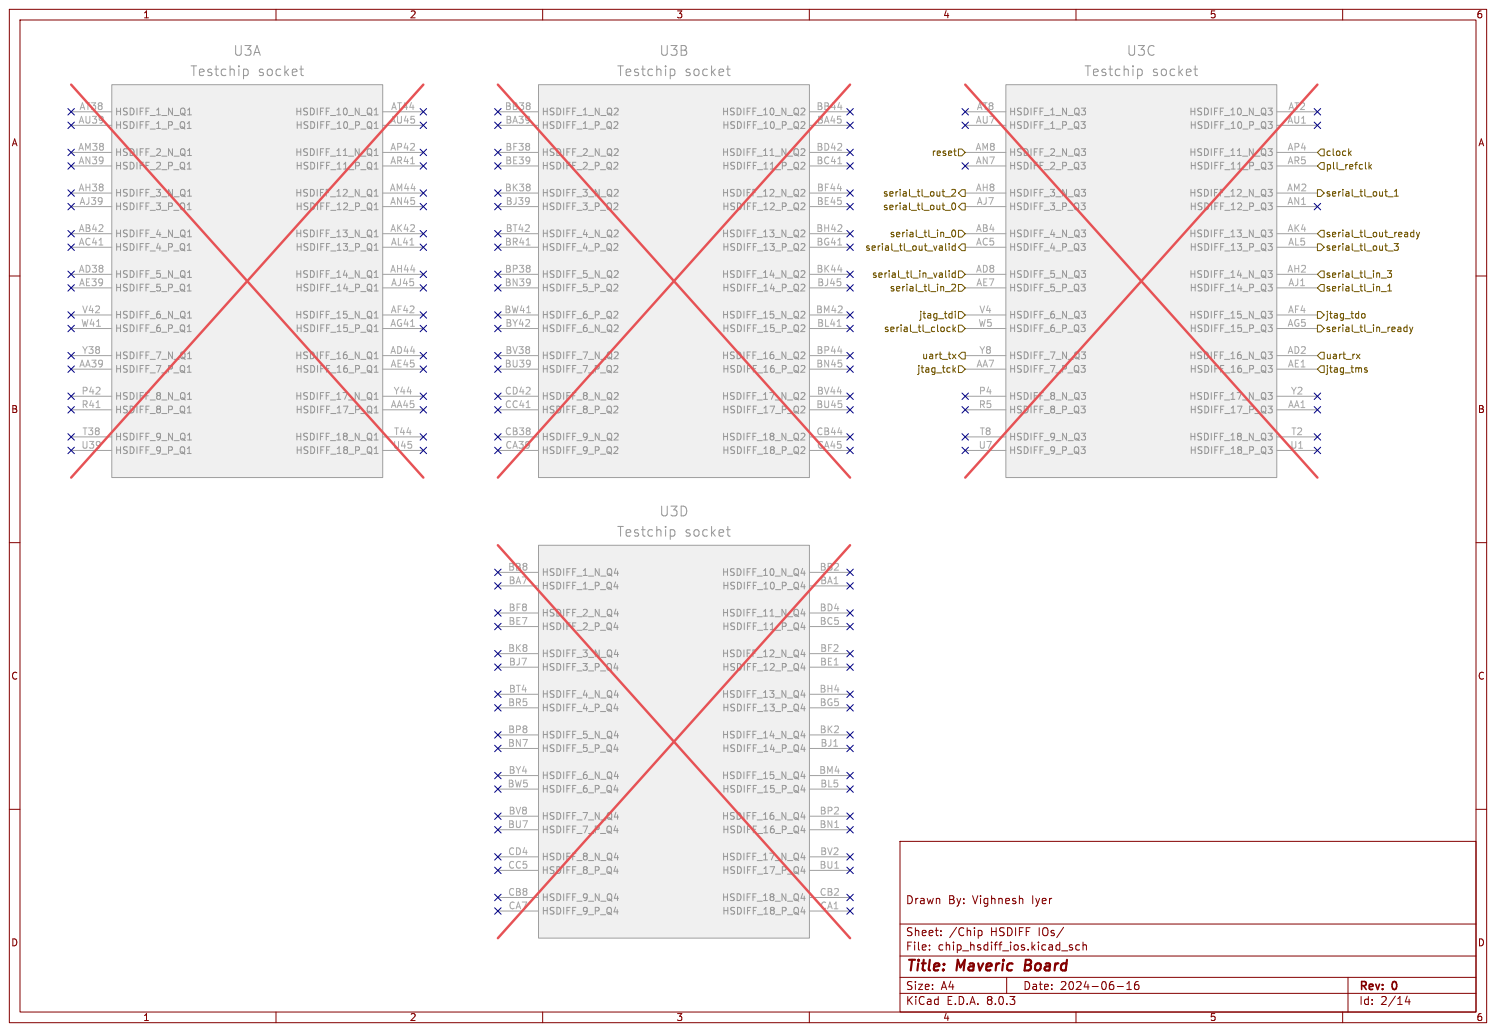
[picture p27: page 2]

Id: 2/14 Title: Maveric Board

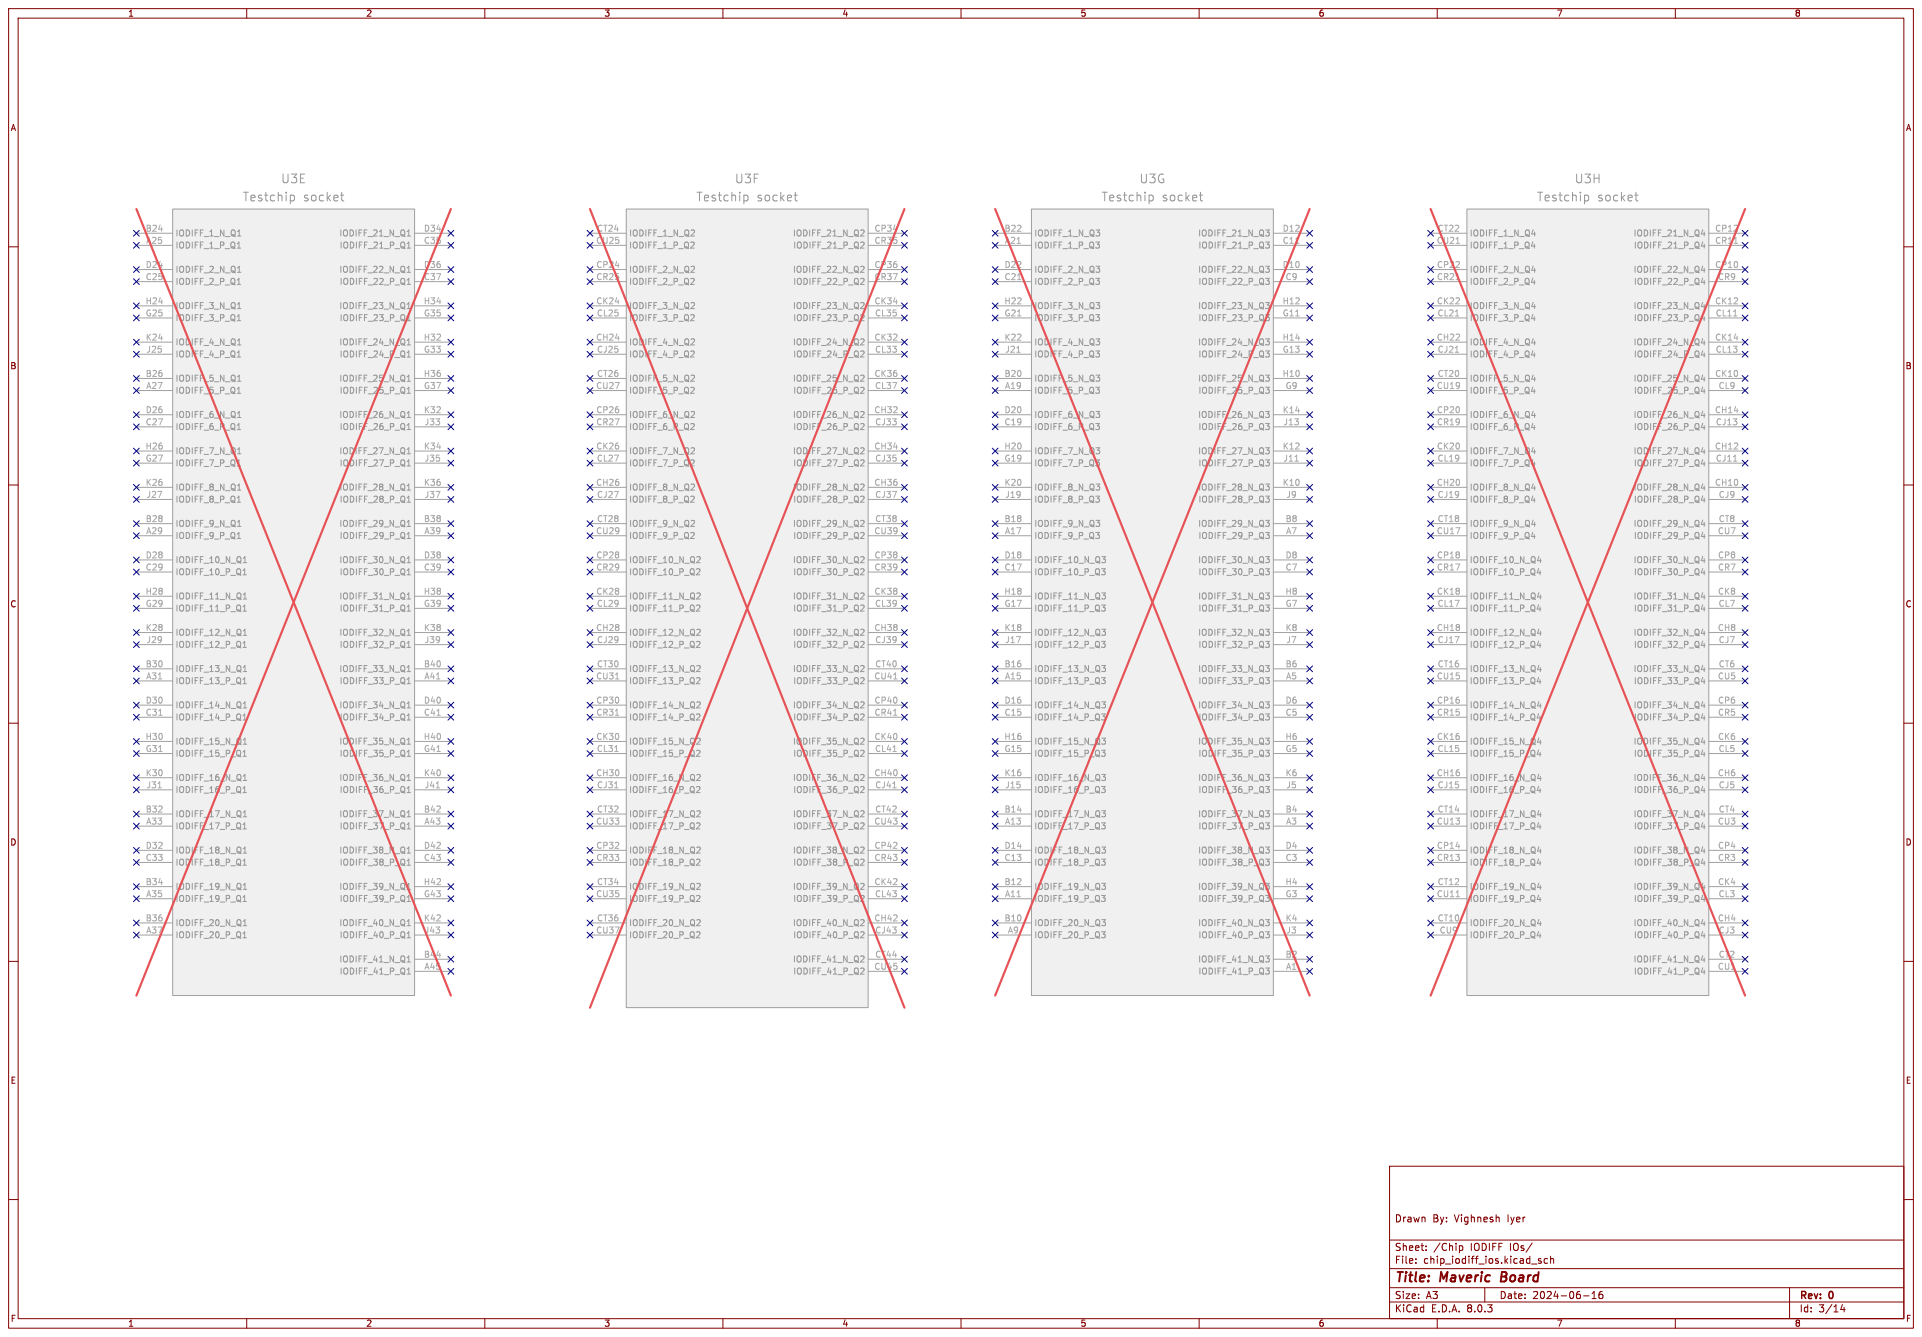
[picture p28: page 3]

File: chip_iodiff_ios.kicad_sch Sheet: /Chip IODIFF IOs/ Drawn By: Vighnesh Iyer

Id: 3/14 Title: Maveric Board

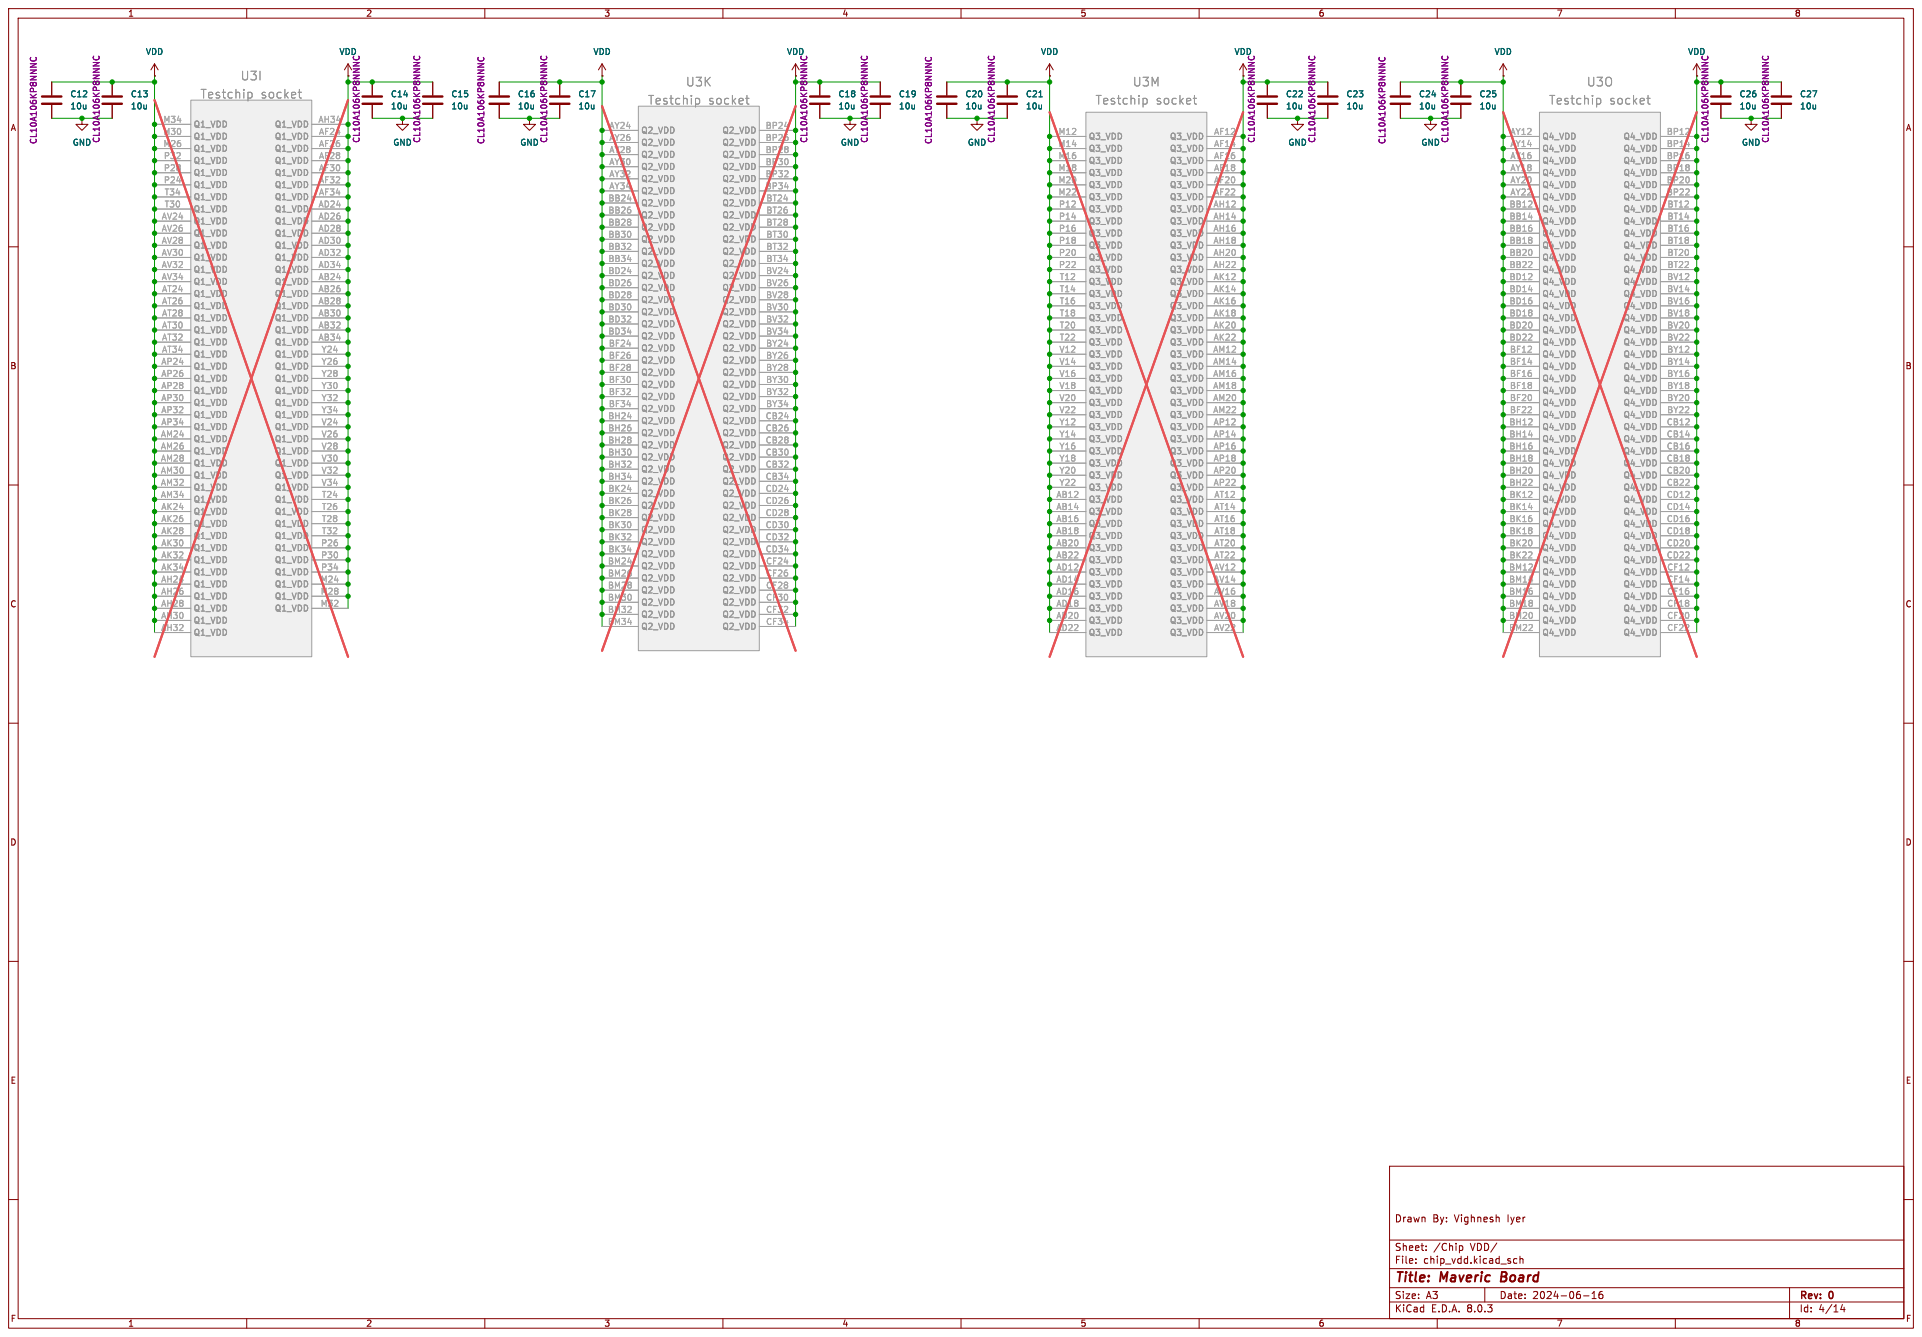
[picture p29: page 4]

File: chip_vdd.kicad_sch Sheet: /Chip VDD/ Drawn By: Vighnesh Iyer

Id: 4/14 Title: Maveric Board

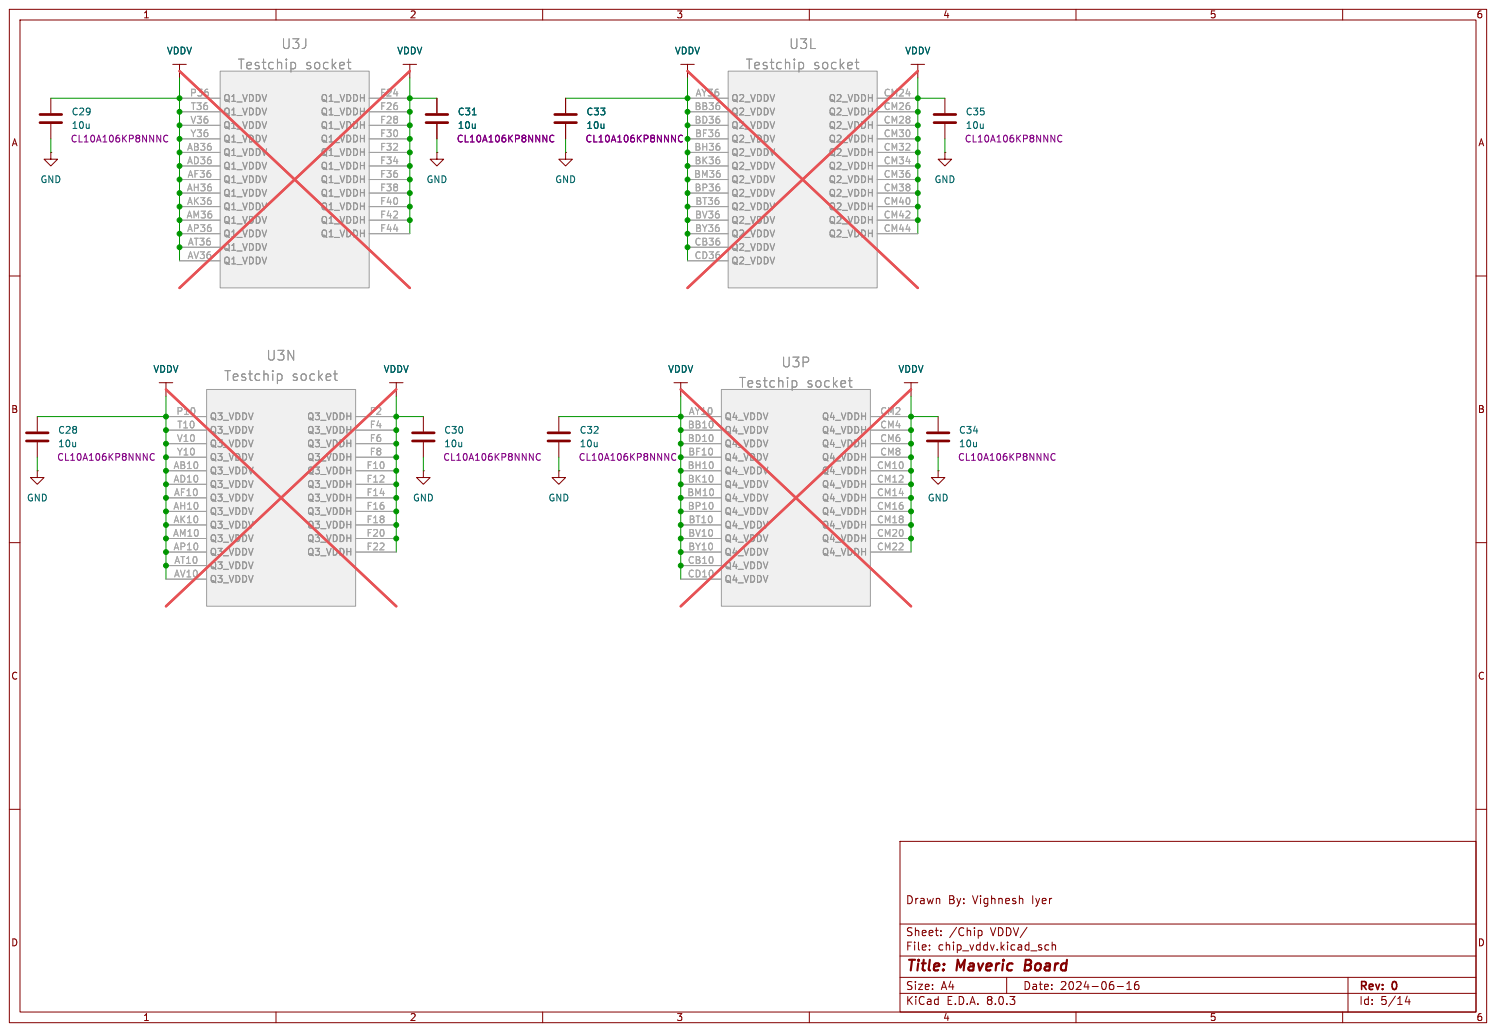
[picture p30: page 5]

Id: 5/14 Title: Maveric Board

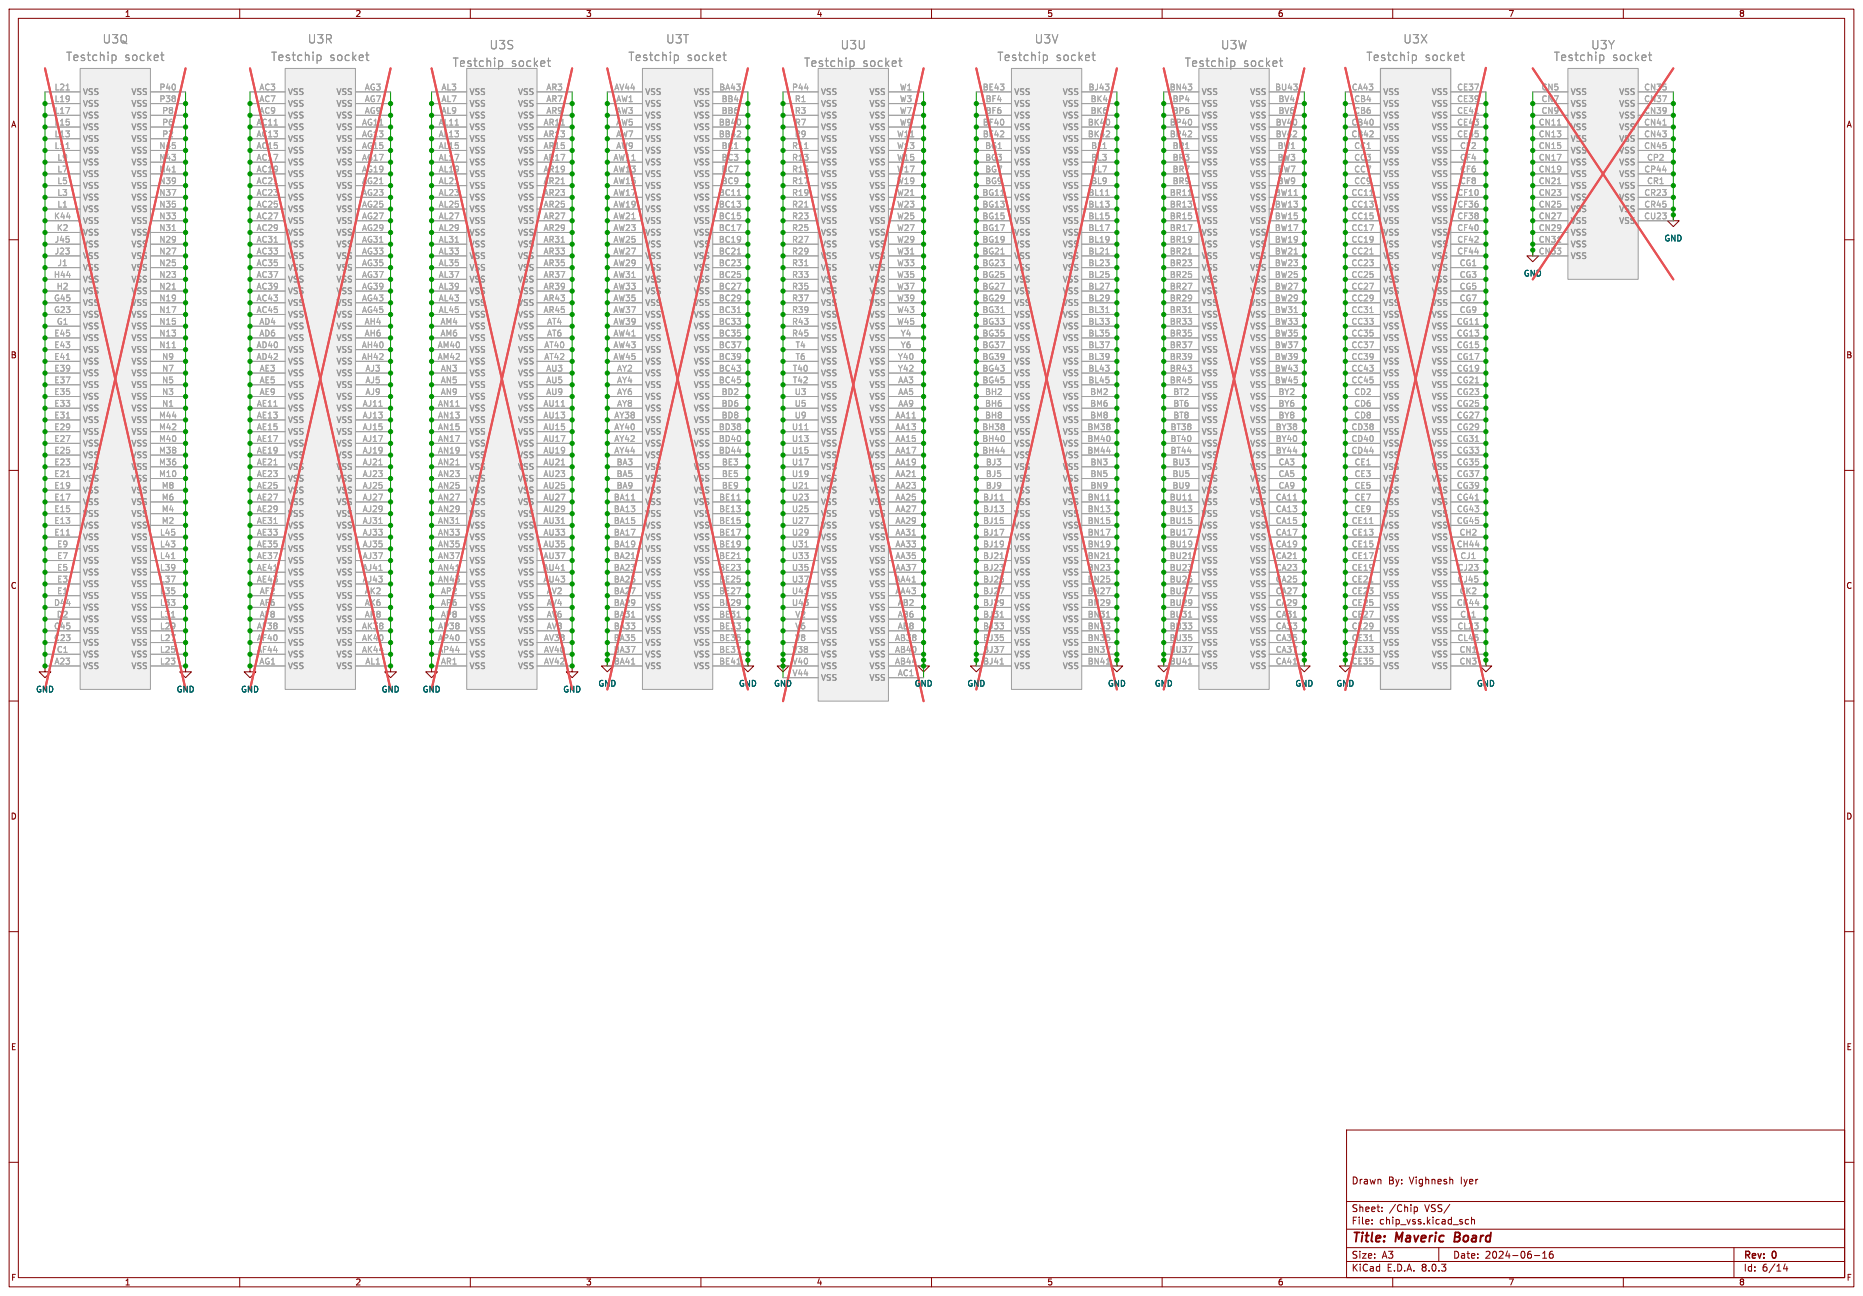
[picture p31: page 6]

File: chip_vss.kicad_sch Sheet: /Chip VSS/ Drawn By: Vighnesh Iyer

Id: 6/14 Title: Maveric Board

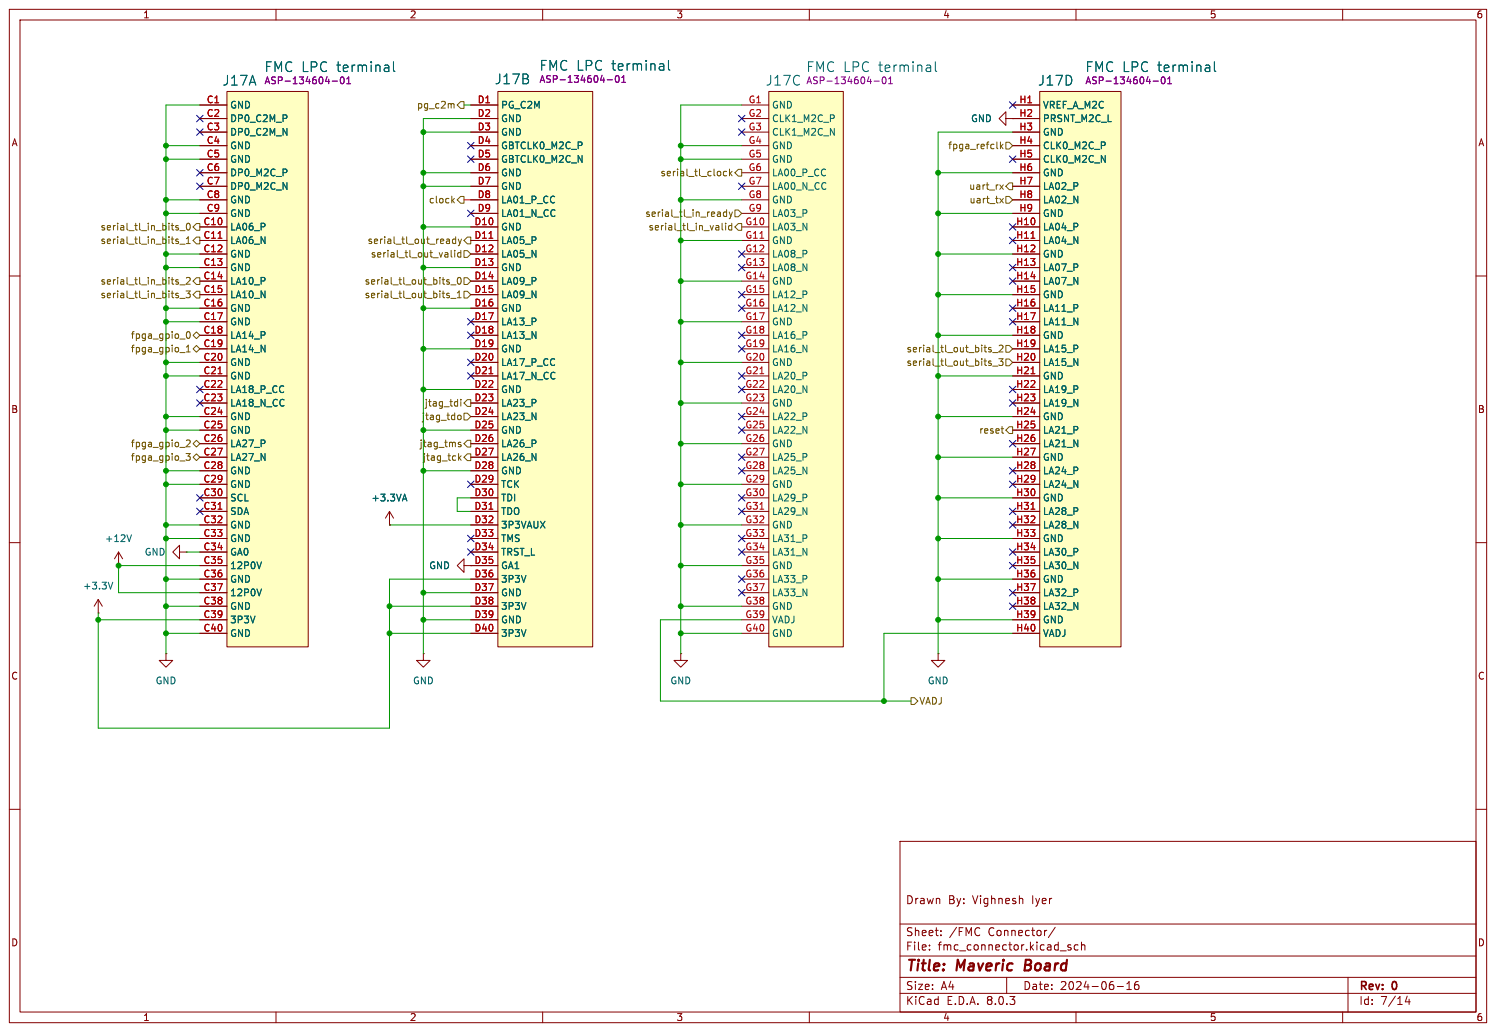
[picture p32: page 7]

FMC LPC terminal ASP-134604-01 GND GND C1
FMC LPC terminal ASP-134604-01 GND C1
3P3V C39 GND C4 GND C40 GND C5 DP0_M2C_P C6 DP0_M2C_N C7 GND C8 GND C9 J17A
LA14_N C19 DP0_C2M_P C2 GND C20 GND C21
LA27_N C27 GND C28 GND C29 DP0_C2M_N C3 SCL C30 SDA C31 GND C32 GND C33 GA0 C34

FMC LPC terminal ASP-134604-01 +3.3V

FMC LPC terminal ASP-134604-01

Id: 7/14 Title: Maveric Board

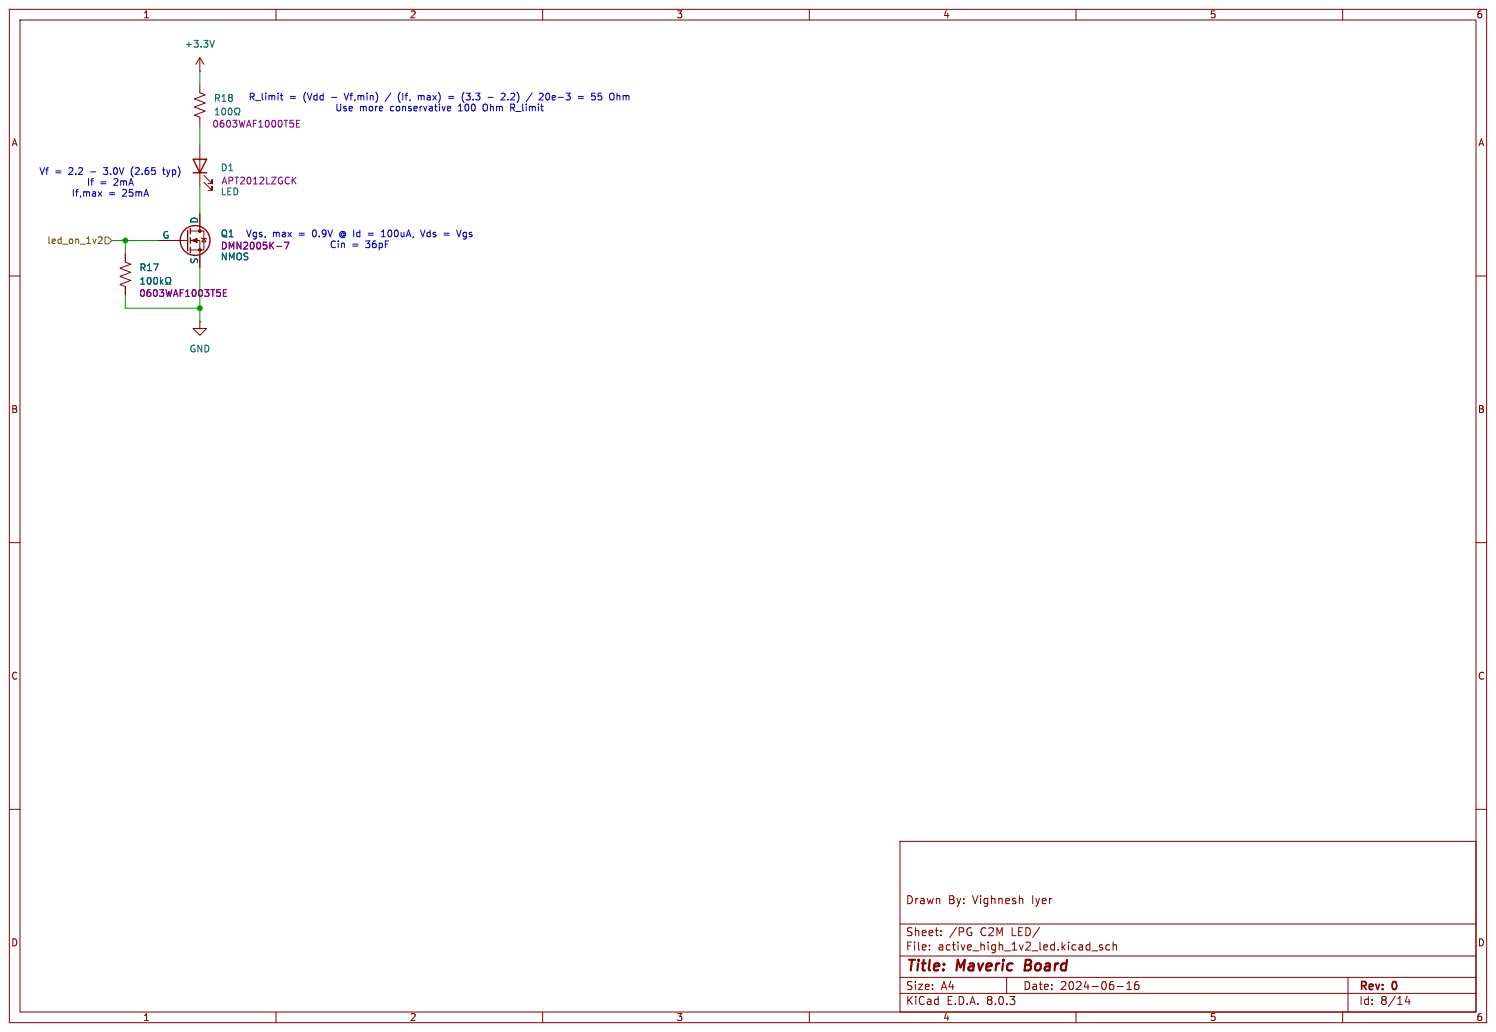
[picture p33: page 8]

Id: 8/14 Title: Maveric Board


Id: 9/14 Title: Maveric Board


Id: 10/14 Title: Maveric Board


Id: 11/14 Title: Maveric Board


Id: 12/14 Title: Maveric Board


þÿ50©(trace) Use FPGA clock with SMA cable

þÿ50©(series impedance) FPGA

Id: 13/14 Title: Maveric Board


Id: 14/14 Title: Maveric Board







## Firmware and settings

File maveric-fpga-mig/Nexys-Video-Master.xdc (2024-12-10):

### This file is a general .xdc for the Nexys Video Rev. A
### To use it in a project:
### - uncomment the lines corresponding to used pins
### - rename the used ports (in each line, after get_ports) according to the top level signal names in the project


## Clock Signal
set_property -dict { PACKAGE_PIN R4    IOSTANDARD LVCMOS33 } [get_ports { sys_clk }]; #IO_L13P_T2_MRCC_34 Sch=sysclk
create_clock -add -name sys_clk_pin -period 10.00 -waveform {0 5} [get_ports sys_clk]

## FMC Transceiver clocks (Must be set to value provided by Mezzanine card, currently set to 156.25 MHz)
## Note: This clock is attached to a MGTREFCLK pin
#set_property -dict { PACKAGE_PIN E6 } [get_ports { GTP_CLK_N }];
#set_property -dict { PACKAGE_PIN F6 } [get_ports { GTP_CLK_P }];
#create_clock -add -name gtpclk0_pin -period 6.400 -waveform {0 3.200} [get_ports {GTP_CLK_P}];
#set_property -dict { PACKAGE_PIN E10 } [get_ports { FMC_MGT_CLK_N }];
#set_property -dict { PACKAGE_PIN F10 } [get_ports { FMC_MGT_CLK_P }];
#create_clock -add -name mgtclk1_pin -period 6.400 -waveform {0 3.200} [get_ports {FMC_MGT_CLK_P}];


## LEDs
set_property -dict { PACKAGE_PIN T14   IOSTANDARD LVCMOS25 } [get_ports { led[0] }]; #IO_L15P_T2_DQS_13 Sch=led[0]
set_property -dict { PACKAGE_PIN T15   IOSTANDARD LVCMOS25 } [get_ports { led[1] }]; #IO_L15N_T2_DQS_13 Sch=led[1]
set_property -dict { PACKAGE_PIN T16   IOSTANDARD LVCMOS25 } [get_ports { led[2] }]; #IO_L17P_T2_13 Sch=led[2]
set_property -dict { PACKAGE_PIN U16   IOSTANDARD LVCMOS25 } [get_ports { led[3] }]; #IO_L17N_T2_13 Sch=led[3]
set_property -dict { PACKAGE_PIN V15   IOSTANDARD LVCMOS25 } [get_ports { led[4] }]; #IO_L14N_T2_SRCC_13 Sch=led[4]
set_property -dict { PACKAGE_PIN W16   IOSTANDARD LVCMOS25 } [get_ports { led[5] }]; #IO_L16N_T2_13 Sch=led[5]
set_property -dict { PACKAGE_PIN W15   IOSTANDARD LVCMOS25 } [get_ports { led[6] }]; #IO_L16P_T2_13 Sch=led[6]
set_property -dict { PACKAGE_PIN Y13   IOSTANDARD LVCMOS25 } [get_ports { led[7] }]; #IO_L5P_T0_13 Sch=led[7]


## Buttons
set_property -dict { PACKAGE_PIN B22 IOSTANDARD LVCMOS12 } [get_ports { reset }]; #IO_L20N_T3_16 Sch=btnc
#set_property -dict { PACKAGE_PIN D22 IOSTANDARD LVCMOS12 } [get_ports { btnd }]; #IO_L22N_T3_16 Sch=btnd
#set_property -dict { PACKAGE_PIN C22 IOSTANDARD LVCMOS12 } [get_ports { btnl }]; #IO_L20P_T3_16 Sch=btnl
#set_property -dict { PACKAGE_PIN D14 IOSTANDARD LVCMOS12 } [get_ports { btnr }]; #IO_L6P_T0_16 Sch=btnr
#set_property -dict { PACKAGE_PIN F15 IOSTANDARD LVCMOS12 } [get_ports { btnu }]; #IO_0_16 Sch=btnu
#set_property -dict { PACKAGE_PIN G4  IOSTANDARD LVCMOS15 } [get_ports { reset }]; #IO_L12N_T1_MRCC_35 Sch=cpu_resetn


## Switches
#set_property -dict { PACKAGE_PIN E22  IOSTANDARD LVCMOS12 } [get_ports { sw[0] }]; #IO_L22P_T3_16 Sch=sw[0]
#set_property -dict { PACKAGE_PIN F21  IOSTANDARD LVCMOS12 } [get_ports { sw[1] }]; #IO_25_16 Sch=sw[1]
#set_property -dict { PACKAGE_PIN G21  IOSTANDARD LVCMOS12 } [get_ports { sw[2] }]; #IO_L24P_T3_16 Sch=sw[2]
#set_property -dict { PACKAGE_PIN G22  IOSTANDARD LVCMOS12 } [get_ports { sw[3] }]; #IO_L24N_T3_16 Sch=sw[3]
#set_property -dict { PACKAGE_PIN H17  IOSTANDARD LVCMOS12 } [get_ports { sw[4] }]; #IO_L6P_T0_15 Sch=sw[4]
#set_property -dict { PACKAGE_PIN J16  IOSTANDARD LVCMOS12 } [get_ports { sw[5] }]; #IO_0_15 Sch=sw[5]
#set_property -dict { PACKAGE_PIN K13  IOSTANDARD LVCMOS12 } [get_ports { sw[6] }]; #IO_L19P_T3_A22_15 Sch=sw[6]
#set_property -dict { PACKAGE_PIN M17  IOSTANDARD LVCMOS12 } [get_ports { sw[7] }]; #IO_25_15 Sch=sw[7]


## OLED Display
#set_property -dict { PACKAGE_PIN W22   IOSTANDARD LVCMOS33 } [get_ports { oled_dc }]; #IO_L7N_T1_D10_14 Sch=oled_dc
#set_property -dict { PACKAGE_PIN U21   IOSTANDARD LVCMOS33 } [get_ports { oled_res }]; #IO_L4N_T0_D05_14 Sch=oled_res
#set_property -dict { PACKAGE_PIN W21   IOSTANDARD LVCMOS33 } [get_ports { oled_sclk }]; #IO_L7P_T1_D09_14 Sch=oled_sclk
#set_property -dict { PACKAGE_PIN Y22   IOSTANDARD LVCMOS33 } [get_ports { oled_sdin }]; #IO_L9N_T1_DQS_D13_14 Sch=oled_sdin
#set_property -dict { PACKAGE_PIN P20   IOSTANDARD LVCMOS33 } [get_ports { oled_vbat }]; #IO_0_14 Sch=oled_vbat
#set_property -dict { PACKAGE_PIN V22   IOSTANDARD LVCMOS33 } [get_ports { oled_vdd }]; #IO_L3N_T0_DQS_EMCCLK_14 Sch=oled_vdd
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

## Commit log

2024-06-10 bumpmap + some more notes + uni2 socket symbol
    [C4 Bump map for UNI2 package.xlsx, Sample-BOM_JLCSMT.xlsx, maveric-board.kicad_pcb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]
2024-06-10 wire up uni2 socket symbol
    [chip_hsdiff_ios.kicad_sch, chip_iodiff_ios.kicad_sch, chip_vdd.kicad_sch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]
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2024-06-10 add pll_refclk
    [chip_hsdiff_ios.kicad_sch]
2024-06-10 add fmc lpc symbol
    [chip_hsdiff_ios.kicad_sch, chip_iodiff_ios.kicad_sch, chip_vdd.kicad_sch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]
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2024-06-10 initial connection of fmc connector
    [fmc_connector.kicad_sch, maveric-board.kicad_sch]
2024-06-11 pick FMC pin mapping
    [fmc_connector.kicad_sch, maveric-board.kicad_sch]
2024-06-11 set and assign all FMC pins, make hierarchical connections
    [fmc_connector.kicad_sch, maveric-board.kicad_sch]
2024-06-11 supplies shorting + probe points text
    [maveric-board.kicad_sch]
2024-06-12 add fmc gpios + make vadj a hier port rather than global supply
    [fmc_connector.kicad_sch, maveric-board.kicad_sch]
2024-06-13 add header pin footprints + debug connections + banana plug connectors
    [24.243.1.stp, 24.243.2.stp, 67996-220HLF.step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]
2024-06-13 added power switch via jumper between vadj and external supplies
    [maveric-board.kicad_sch]
2024-06-13 added uart header for pmod usbuart
    [maveric-board.kicad_sch]
2024-06-13 add level shifters for uart, fix some ERCs
    [SN74AVC1T45DBVR.step, chip_vss.kicad_sch, fmc_connector.kicad_sch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]
2024-06-13 add jtag 20pin header
    [maveric-board.kicad_sch]
2024-06-13 add jlcpcb 10u cap part + footprint
    [chip_vdd.kicad_sch, chip_vddv.kicad_sch]
2024-06-14 pin down parts for led circuit + add footprints
    [APT2012LZGCK.step, DMN2005K-7.step, active_high_1v2_led.kicad_sch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]
2024-06-14 some few notes
    [active_high_1v2_led.kicad_sch]
2024-06-15 wire up the LEDs
    [active_high_1v2_led.kicad_sch, maveric-board.kicad_sch]
2024-06-15 add clocking notes
    [active_high_1v2_led.kicad_sch, maveric-board.kicad_sch]
2024-06-16 figure out stackup and 50ohm trace width
    [maveric-board.kicad_sch]
2024-06-16 add clocking stuff to schematic + sma jack footprint
    [c-5-1814832-2-c-3d.stp, clocking _diagram.kicad_sch, maveric-board.kicad_sch]
2024-06-16 reannotate, fix all ERCs
    [active_high_1v2_led.kicad_sch, chip_hsdiff_ios.kicad_sch, chip_iodiff_ios.kicad_sch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]
2024-06-16 add uni2 socket footprint, check against drawing, fix npth, assign all footprints and part numbers
    [active_high_1v2_led.kicad_sch, chip_hsdiff_ios.kicad_sch, chip_iodiff_ios.kicad_sch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]
2024-06-16 fix sheet name
    [clocking_diagram.kicad_sch, maveric-board.kicad_sch]
2024-06-16 add bulk decap + decap for uart level shifters
    [maveric-board.kicad_sch]
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2024-06-16 add testpoint for pg_c2m and fixup footprints for led and mosfet with correct pin mapping
    [active_high_1v2_led.kicad_sch, chip_vdd.kicad_sch, chip_vddv.kicad_sch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]
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2024-06-16 some docs + dnp uni2 socket
    [chip_hsdiff_ios.kicad_sch, chip_iodiff_ios.kicad_sch, chip_vdd.kicad_sch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]
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2024-06-16 add stackup + layer assignments
    [maveric-board.kicad_pcb]
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2024-06-17 initial placement and edge cuts
    [68001-103HLF.step, active_high_1v2_led.kicad_sch, maveric-board.kicad_pcb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]
2024-06-17 add mfr part # attribute to each symbol, resync board layout, remove excess VDDV decap
    [active_high_1v2_led.kicad_sch, chip_vdd.kicad_sch, chip_vddv.kicad_sch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]
2024-06-17 some tinkering with placement
    [maveric-board.kicad_pcb]
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2024-06-18 add all silks for debug
    [maveric-board.kicad_pcb, maveric-board.kicad_sch]
2024-06-18 remove big power probe header and use tiny one to simplify routing
    [maveric-board.kicad_pcb, maveric-board.kicad_sch]
2024-06-18 redo placement for the tenth time
    [maveric-board.kicad_pcb]
2024-06-19 do some more routing
    [maveric-board.kicad_pcb]
2024-06-19 ok, i need to replace the level shifters
    [maveric-board.kicad_pcb]
2024-06-20 notes from schematic review
    [maveric-board.kicad_pcb]
2024-06-20 fix bump mapping
    [chip_hsdiff_ios.kicad_sch]
2024-06-21 add reset button, add 3d model for uni2 socket, move 3d models into directory
    [24.243.1.stp, 24.243.2.stp, 67996-220HLF.step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]
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2024-06-22 add pmod right angle 6 pin header
    [HDR-TH_6P-P2.54-H-F-W5.7.step, maveric-board.kicad_sch]
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2024-06-22 add probe smt hooks for grounds and supplies
    [TESTPOINT-SMD_L3.8-W2.0_RH-5019.step, maveric-board.kicad_sch]
2024-06-22 wire jtag signals through fmc too
    [fmc_connector.kicad_sch, maveric-board.kicad_sch]
2024-06-22 add mounting holes that line up with xem7350 to fmc footprint
    [maveric-board.kicad_pcb]
2024-06-22 swap some extended parts out for basic ones
    [chip_vdd.kicad_sch, chip_vddv.kicad_sch, maveric-board.kicad_sch]
2024-06-22 swap out some more parts, now we only have 12 extended parts = $24 extra fee
    [maveric-board.kicad_sch]
2024-06-22 resync all symbols to schematic, reannotate schematic
    [active_high_1v2_led.kicad_sch, chip_hsdiff_ios.kicad_sch, chip_iodiff_ios.kicad_sch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]
2024-06-23 update layout with new footprints + schematic symbols
    [maveric-board.kicad_pcb]
2024-06-23 reimport from schematic, ready for routing
    [maveric-board.kicad_pcb]
2024-06-24 remap and cleanly route away fpga gpios
    [fmc_connector.kicad_sch, maveric-board.kicad_pcb, maveric-board.kicad_sch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]
2024-06-24 remap and route fmc uart
    [fmc_connector.kicad_sch, maveric-board.kicad_pcb]
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2024-06-27 validate socket symbol and footprint
    [Hyperscale 4x4 Package.xlsx, UNI2 ball map.csv, maveric-board.kicad_pcb]
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2024-06-28 route out all fmc nets on top copper
    [maveric-board.kicad_pcb]
2024-06-30 route nearly all nets to chip
    [maveric-board.kicad_pcb]
2024-06-30 more progress on decap routing
    [maveric-board.kicad_pcb]
2024-07-01 oh this is so intricate
    [maveric-board.kicad_pcb]
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2024-07-01 route some more decap
    [maveric-board.kicad_pcb]
2024-07-02 finish routing all decap
    [maveric-board.kicad_pcb]
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2024-07-02 place all power ground vias
    [maveric-board.kicad_pcb]
2024-07-02 route around vddv bump issue, add some jumpers
    [maveric-board.kicad_pcb]
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2024-07-02 convert some npth to plated
    [maveric-board.kicad_sch]
2024-07-03 fix some drcs, try to fix bga footprint courtyard, still needs tiny adjustment
2024-07-03 fix some silkscreen issues within footprints
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2024-07-03 add jtag pullups/downs + extra debug functionality to schematic
    [maveric-board.kicad_sch]
2024-07-04 fix socket 3d model
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2024-07-05 fixup schematic + redo banana jack footprints to match jlc render
    [AUDIO-TH_24.243.1.step, CONN-TH_24.243.2.step, active_high_1v2_led.kicad_sch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]
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2024-07-10 add images and bom
    [bom.csv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]
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
